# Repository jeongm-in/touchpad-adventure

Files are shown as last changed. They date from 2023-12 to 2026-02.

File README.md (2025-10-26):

# touchpad-adventure

Repurposing [Framework](https://frame.work/)'s [Touchpad module for Framework 13'](https://frame.work/products/touchpad-kit?v=FRANFT0001) as a stand alone device using Raspberry Pi Pico, inspired by [Framework Magic Trackpad](https://community.frame.work/t/framework-magic-trackpad/19453) forum post and [HID articles on Hackaday by Arya Voronova](https://hackaday.com/2024/04/17/human-interfacing-devices-hid-over-i2c/)

## Framework touchpad module
Framework touchpad module is a 115 x 76.6mm glass panel that uses [PixArt PCT3854QR](https://www.pixart.com/products-detail/112/PCT3854QR) controller. Unfortunately PixArt does not provide documentation for this chipset, but it supports HID over I2C which simplifies matters a lot. 

In Framework laptop 13' model, both fingerprint reader and keyboard are connected to the touchpad module. Touchpad module then routes all three fingerprint reader / keyboard / touchpad signals to the motherboard via 51 pin ZIF connector-to-10156001-051100LF connector. Framework provides connector and pinout information on their [GitHub repository](https://github.com/FrameworkComputer/Framework-Laptop-13/tree/main/Touchpad). 

Since this touchpad uses HID over I2C protocol, I'm only interested in 5 out of the 51 pins: TP_SCL (Serial Clock Line), TP_SDA (Serial Data Line), TP_INT (Interrupt, Work in progress to get the INT working), GND, and 5VS.

| Pin | Conn | Signal | Notes|
|-----|----- | --- | ----- |
| 33 | 17 | GND |  |
| 34  | 34 | TP_SCL | Touchpad I2C SCL -- Clock Line|
| 35 | 18 | TP_INT | Touchpad interrupt GPIO | 
| 36 | 33 | TP_SDA | Touchpad I2C SDA -- Data Line | 
| 38 | 32 | 5VS | 5V, Connected to 5VS rail through a 0 ohm resistor |
| 39 | 20 | 5VALW | Fingerprint 5V | 
| 40 | 31 | USB_N | Fingerprint USB | 
| 41 | 21 | GND |  |
| 42 | 20 | USB_P | Fingerprint USB | 
| 37 | 19 | TP_BOARD_ID | |
| 26 | 38 | GND |  |
| 29 | 15 | GND |  |
| 31 | 16 | GND |  |
| 49 | 25 | GND |  | 
| 48 | 27 | FPR_LED_COM | 5V, Fingerprint LED |

Above table shows the pin mapping between the ZIF connector (Pin column) and the 10156001-051100LF connector (Conn column). But since we're not using the 10156001-051100LF connector, this table is not relevant to us. 

Although the pinout says the touchpad module takes 5V input, I found that it works just fine with 3.3V which is found in a lot of microcontrollers. I'll be using Raspberry Pi Pico W for the remainder of this write up. 

## Assembly and probing

I ordered [51 pin ZIF breakout board](https://www.aliexpress.us/item/2251832656865723.html) from AliExpress and soldered headers on it. It looks like I can use any of the numerous GND pins, but I stuck to the one that's closest to my I2C pins. 

| Pin | Breakout board |
| --- |  --- |
| SDA |  36 |
| SCL |  34 | 
| GND |  33 |
| 5V |  40 |
| INT | 35 |

Initially I started out with an [Elite-C](https://deskthority.net/wiki/Elite-C) (Pro-Micro compatible board) running Arduino, because I thought I needed 5V to power the device. After connecting the microcontroller to the touchpad, I used the [I2C scanner sketch](https://playground.arduino.cc/Main/I2cScanner/) to see the available I2C addresses. Framework Touchpad module utilizes two I2C addresses, 0x2C and 0x33:

```
I2C device found at address 0x2C  ! (44)
I2C device found at address 0x33  ! (51)
done
```

Plugging the device to the Raspberry Pi 3B+ and running `i2cdetect` also revealed the same results: 
```
passionfruit@raspberrypi:~ $ i2cdetect -y 1
     0  1  2  3  4  5  6  7  8  9  a  b  c  d  e  f
00:                         -- -- -- -- -- -- -- --
10: -- -- -- -- -- -- -- -- -- -- -- -- -- -- -- --
20: -- -- -- -- -- -- -- -- -- -- -- -- 2c -- -- --
30: -- -- -- 33 -- -- -- -- -- -- -- -- -- -- -- --
40: -- -- -- -- -- -- -- -- -- -- -- -- -- -- -- --
50: -- -- -- -- -- -- -- -- -- -- -- -- -- -- -- --
60: -- -- -- -- -- -- -- -- -- -- -- -- -- -- -- --
70: -- -- -- -- -- -- -- --
```

Additional `i2cdump` results showed that there's something on 0x20 within this address at 0x2C: 

```
passionfruit@raspberrypi:~ $ i2cdump -y 1 0x2c
No size specified (using byte-data access)
     0  1  2  3  4  5  6  7  8  9  a  b  c  d  e  f    0123456789abcdef
00: 00 00 00 00 00 00 00 00 00 00 00 00 00 00 00 00    ................
10: 00 00 00 00 00 00 00 00 00 00 00 00 00 00 00 00    ................
20: 1e 06 00 00 00 00 00 00 00 00 00 00 00 00 00 00    ??..............
30: 00 00 00 00 00 00 00 00 00 00 00 00 00 00 00 00    ................
40: 00 00 00 00 00 00 00 00 00 00 00 00 00 00 00 00    ................
50: 00 00 00 00 00 00 00 00 00 00 00 00 00 00 00 00    ................
60: 00 00 00 00 00 00 00 00 00 00 00 00 00 00 00 00    ................
70: 00 00 00 00 00 00 00 00 00 00 00 00 00 00 00 00    ................
80: 00 00 00 00 00 00 00 00 00 00 00 00 00 00 00 00    ................
90: 00 00 00 00 00 00 00 00 00 00 00 00 00 00 00 00    ................
a0: 00 00 00 00 00 00 00 00 00 00 00 00 00 00 00 00    ................
b0: 00 00 00 00 00 00 00 00 00 00 00 00 00 00 00 00    ................
c0: 00 00 00 00 00 00 00 00 00 00 00 00 00 00 00 00    ................
d0: 00 00 00 00 00 00 00 00 00 00 00 00 00 00 00 00    ................
e0: 00 00 00 00 00 00 00 00 00 00 00 00 00 00 00 00    ................
f0: 00 00 00 00 00 00 00 00 00 00 00 00 00 00 00 00    ................
```

Then by pure luck, I learned that the device works just fine with 3.3V so I switched over to Raspberry Pi Pico W so that I can use micropython instead of Arduino code. This turned out to be a good decision because Arduino's Wire library by default reads less number of bytes than the HID input report sent from the touchpad module. And I was constantly hitting memory limit on Elite-C, though that's probably because my code was horribly inefficient.  

With some trial and error, I wrote some code based on the Python code provided in [Arya's Hackaday article](https://hackaday.com/2024/04/17/human-interfacing-devices-hid-over-i2c/) to read some data out of 0x2c - 0x20 on the touchpad device.

```python
# Scan for connected I2C devices  
import machine

SDA_PIN = machine.Pin(4)
SCL_PIN = machine.Pin(5)
i2c = machine.I2C(0, sda=SDA_PIN, scl=SCL_PIN, freq=500000)

TOUCHPAD_ADDR = 0x2c
REPORT_ID = 0x01 

def helper_function(abc):
    return ([abc[i:i+2] for i in range(0, len(abc), 2)])

def helper_function_to_int(myList):
    k = [int(x, 16) for x in myList]
    v = ["{:03d}".format(x) for x in k]
    return  [str(x) for x in v]

def runner():
    while True:
        try:
            l = i2c.readfrom(TOUCHPAD_ADDR, 1)[0]
            if l:
                d = i2c.readfrom(TOUCHPAD_ADDR, l)
                if d[2] != REPORT_ID:
                    print("WARNING")
                    print(l, d)
                else:
                    d = d[3:]
                    formatted = helper_function(d.hex())
                    output = helper_function_to_int(formatted)
                    print(" ".join(output))
                    
        except OSError:
            print("Nothing burger")

runner()
```

Using this code, I was able to consistently read 30 something bytes long data that changed every time I moved the finger around. It also changed depending on the number of fingers contacting the touchpad surface. This byte array was the actual HID input report sent from the device, but I did not understand what it meant at the time. 

## Finding HID report descriptor and understanding the report 

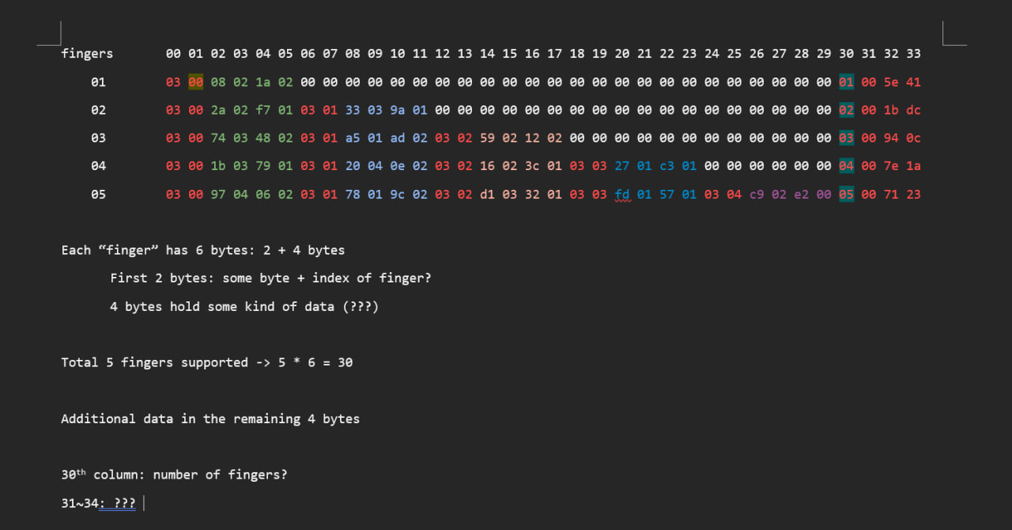
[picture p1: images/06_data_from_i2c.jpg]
table


I made some best effort guesses to figure out what this data meant. But to really understand what is going on, I had to look at the HID report descriptor used by this touchpad device. 

HID Report is nothing more than a binary data sent from the HID device. HID Report descriptor is a schematic for a given HID report, which outlines what each parts of the report's binary data means and describes the range limit of each part. 

I had some data to work with, such as report descriptor data in [Arya's repository](https://github.com/0xAryaCAFE/spicy-micropython/blob/3810a95b423668ce8a7be2f6eb615eec5d33fedd/ports/rp2/tusb_port.c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). Apparently Arya and many other people were already here, but I couldn't readily find a way to turn this module into a stand alone device online.

I also learned that HID device usually stores its HID descriptor on the device so that the host machine can interact with it. I updated my earlier code to "dump" some data from each address under 0x2C. 

```python
def helper_function_to_int(myList):
    k = [int(x, 16) for x in myList]
    v = ["{:03d}".format(x) for x in k]
    return  [str(x) for x in v]

def brute_force():
    for i in range(0, 256):
        l = i2c.readfrom_mem(TOUCHPAD_ADDR, i, 64)
        print(i, " ".join(helper_function(l.hex())))
```

```bash
...
30 00 00 00 01 af 02 21 00 24 00 25 00 25 00 00 00 22 00 23 00 3a 09 74 02 04 07 00 00 00 00 00 00 00 03 00 91 f5 00 00 00 00 00 00 00 00 00 00 00 00 00 00 00 00 00 00 00 00 00 00 00 00 00 00 00
31 00 00 00 01 af 02 21 00 24 00 25 00 25 00 00 00 22 00 23 00 3a 09 74 02 04 07 00 00 00 00 00 00 00 03 00 91 f5 00 00 00 00 00 00 00 00 00 00 00 00 00 00 00 00 00 00 00 00 00 00 00 00 00 00 00

// ↓↓↓↓↓↓↓↓↓↓↓↓↓↓↓↓↓↓↓↓↓↓↓↓↓↓↓↓↓↓↓
32 1e 00 00 01 af 02 21 00 24 00 25 00 25 00 00 00 22 00 23 00 3a 09 74 02 04 07 00 00 00 00 00 00 00 00 00 00 00 00 00 00 00 00 00 00 00 00 00 00 00 00 00 00 00 00 00 00 00 00 00 00 00 00 00 00

// ↓↓↓↓↓↓↓↓↓↓↓↓↓↓↓↓↓↓↓↓↓↓↓↓↓↓↓↓↓↓↓
33 05 01 09 02 a1 01 85 02 05 01 09 01 a1 00 05 09 19 01 29 02 15 00 25 01 75 01 95 02 81 02 05 0d 09 32 75 01 95 01 81 02 75 05 95 01 81 03 05 01 75 10 95 01 35 00 45 00 16 00 80 26 ff 7f 09 30

34 00 00 00 01 af 02 21 00 24 00 25 00 25 00 00 00 22 00 23 00 3a 09 74 02 04 07 00 00 00 00 00 00 00 03 00 91 f5 00 00 00 00 00 00 00 00 00 00 00 00 00 00 00 00 00 00 00 00 00 00 00 00 00 00 00
35 00 00 00 01 af 02 21 00 24 00 25 00 25 00 00 00 22 00 23 00 3a 09 74 02 04 07 00 00 00 00 00 00 00 03 00 91 f5 00 00 00 00 00 00 00 00 00 00 00 00 00 00 00 00 00 00 00 00 00 00 00 00 00 00 00
...
```

And of course, the report descriptor was stored under 0x33. Using [Frank Zhao's USB Descriptor and Request Parser tool](https://eleccelerator.com/usbdescreqparser/), here's the HID report descriptor for the Framework's touchpad module.

```
0x05, 0x01,        // Usage Page (Generic Desktop Ctrls)
0x09, 0x02,        // Usage (Mouse)
0xA1, 0x01,        // Collection (Application)
0x85, 0x02,        //   Report ID (2)
0x05, 0x01,        //   Usage Page (Generic Desktop Ctrls)
0x09, 0x01,        //   Usage (Pointer)
0xA1, 0x00,        //   Collection (Physical)
0x05, 0x09,        //     Usage Page (Button)
0x19, 0x01,        //     Usage Minimum (0x01)
0x29, 0x02,        //     Usage Maximum (0x02)
0x15, 0x00,        //     Logical Minimum (0)
0x25, 0x01,        //     Logical Maximum (1)
0x75, 0x01,        //     Report Size (1)
0x95, 0x02,        //     Report Count (2)
0x81, 0x02,        //     Input (Data,Var,Abs,No Wrap,Linear,Preferred State,No Null Position)
0x05, 0x0D,        //     Usage Page (Digitizer)
0x09, 0x32,        //     Usage (In Range)
0x75, 0x01,        //     Report Size (1)
0x95, 0x01,        //     Report Count (1)
0x81, 0x02,        //     Input (Data,Var,Abs,No Wrap,Linear,Preferred State,No Null Position)
0x75, 0x05,        //     Report Size (5)
0x95, 0x01,        //     Report Count (1)
0x81, 0x03,        //     Input (Const,Var,Abs,No Wrap,Linear,Preferred State,No Null Position)
0x05, 0x01,        //     Usage Page (Generic Desktop Ctrls)
0x75, 0x10,        //     Report Size (16)
0x95, 0x01,        //     Report Count (1)
0x35, 0x00,        //     Physical Minimum (0)
0x45, 0x00,        //     Physical Maximum (0)
0x16, 0x00, 0x80,  //     Logical Minimum (-32768)
0x26, 0xFF, 0x7F,  //     Logical Maximum (32767)
0x09, 0x30,        //     Usage (X)
0x81, 0x26,        //     Input (Data,Var,Rel,No Wrap,Linear,No Preferred State,No Null Position)
0x16, 0x00, 0x80,  //     Logical Minimum (-32768)
0x26, 0xFF, 0x7F,  //     Logical Maximum (32767)
0x09, 0x31,        //     Usage (Y)
0x81, 0x26,        //     Input (Data,Var,Rel,No Wrap,Linear,No Preferred State,No Null Position)
0xC0,              //   End Collection
0xC0,              // End Collection
0x05, 0x0D,        // Usage Page (Digitizer)
0x09, 0x05,        // Usage (Touch Pad)
0xA1, 0x01,        // Collection (Application)
0x85, 0x01,        //   Report ID (1)
0x05, 0x0D,        //   Usage Page (Digitizer)
0x09, 0x22,        //   Usage (Finger)
0xA1, 0x02,        //   Collection (Logical)
0x09, 0x47,        //     Usage (0x47)
0x09, 0x42,        //     Usage (Tip Switch)
0x15, 0x00,        //     Logical Minimum (0)
0x25, 0x01,        //     Logical Maximum (1)
0x75, 0x01,        //     Report Size (1)
0x95, 0x02,        //     Report Count (2)
0x81, 0x02,        //     Input (Data,Var,Abs,No Wrap,Linear,Preferred State,No Null Position)
0x95, 0x06,        //     Report Count (6)
0x81, 0x03,        //     Input (Const,Var,Abs,No Wrap,Linear,Preferred State,No Null Position)
0x09, 0x51,        //     Usage (0x51)
0x25, 0x0F,        //     Logical Maximum (15)
0x75, 0x08,        //     Report Size (8)
0x95, 0x01,        //     Report Count (1)
0x81, 0x02,        //     Input (Data,Var,Abs,No Wrap,Linear,Preferred State,No Null Position)
0x05, 0x01,        //     Usage Page (Generic Desktop Ctrls)
0x09, 0x30,        //     Usage (X)
0x75, 0x10,        //     Report Size (16)
0x55, 0x0E,        //     Unit Exponent (-2)
0x65, 0x11,        //     Unit (System: SI Linear, Length: Centimeter)
0x35, 0x00,        //     Physical Minimum (0)
0x46, 0x5A, 0x04,  //     Physical Maximum (1114)
0x27, 0x39, 0x05, 0x00, 0x00,  //     Logical Maximum (1336)
0x81, 0x02,        //     Input (Data,Var,Abs,No Wrap,Linear,Preferred State,No Null Position)
0x09, 0x31,        //     Usage (Y)
0x46, 0xDA, 0x02,  //     Physical Maximum (730)
0x27, 0x6C, 0x03, 0x00, 0x00,  //     Logical Maximum (875)
0x81, 0x02,        //     Input (Data,Var,Abs,No Wrap,Linear,Preferred State,No Null Position)
0xC0,              //   End Collection
0x05, 0x0D,        //   Usage Page (Digitizer)
0x09, 0x22,        //   Usage (Finger)
0xA1, 0x02,        //   Collection (Logical)
0x09, 0x47,        //     Usage (0x47)
0x09, 0x42,        //     Usage (Tip Switch)
0x15, 0x00,        //     Logical Minimum (0)
0x25, 0x01,        //     Logical Maximum (1)
0x75, 0x01,        //     Report Size (1)
0x95, 0x02,        //     Report Count (2)
0x81, 0x02,        //     Input (Data,Var,Abs,No Wrap,Linear,Preferred State,No Null Position)
0x95, 0x06,        //     Report Count (6)
0x81, 0x03,        //     Input (Const,Var,Abs,No Wrap,Linear,Preferred State,No Null Position)
0x09, 0x51,        //     Usage (0x51)
0x25, 0x0F,        //     Logical Maximum (15)
0x75, 0x08,        //     Report Size (8)
0x95, 0x01,        //     Report Count (1)
0x81, 0x02,        //     Input (Data,Var,Abs,No Wrap,Linear,Preferred State,No Null Position)
0x05, 0x01,        //     Usage Page (Generic Desktop Ctrls)
0x09, 0x30,        //     Usage (X)
0x75, 0x10,        //     Report Size (16)
0x55, 0x0E,        //     Unit Exponent (-2)
0x65, 0x11,        //     Unit (System: SI Linear, Length: Centimeter)
0x35, 0x00,        //     Physical Minimum (0)
0x46, 0x5A, 0x04,  //     Physical Maximum (1114)
0x27, 0x39, 0x05, 0x00, 0x00,  //     Logical Maximum (1336)
0x81, 0x02,        //     Input (Data,Var,Abs,No Wrap,Linear,Preferred State,No Null Position)
0x09, 0x31,        //     Usage (Y)
0x46, 0xDA, 0x02,  //     Physical Maximum (730)
0x27, 0x6C, 0x03, 0x00, 0x00,  //     Logical Maximum (875)
0x81, 0x02,        //     Input (Data,Var,Abs,No Wrap,Linear,Preferred State,No Null Position)
0xC0,              //   End Collection
0x05, 0x0D,        //   Usage Page (Digitizer)
0x09, 0x22,        //   Usage (Finger)
0xA1, 0x02,        //   Collection (Logical)
0x09, 0x47,        //     Usage (0x47)
0x09, 0x42,        //     Usage (Tip Switch)
0x15, 0x00,        //     Logical Minimum (0)
0x25, 0x01,        //     Logical Maximum (1)
0x75, 0x01,        //     Report Size (1)
0x95, 0x02,        //     Report Count (2)
0x81, 0x02,        //     Input (Data,Var,Abs,No Wrap,Linear,Preferred State,No Null Position)
0x95, 0x06,        //     Report Count (6)
0x81, 0x03,        //     Input (Const,Var,Abs,No Wrap,Linear,Preferred State,No Null Position)
0x09, 0x51,        //     Usage (0x51)
0x25, 0x0F,        //     Logical Maximum (15)
0x75, 0x08,        //     Report Size (8)
0x95, 0x01,        //     Report Count (1)
0x81, 0x02,        //     Input (Data,Var,Abs,No Wrap,Linear,Preferred State,No Null Position)
0x05, 0x01,        //     Usage Page (Generic Desktop Ctrls)
0x09, 0x30,        //     Usage (X)
0x75, 0x10,        //     Report Size (16)
0x55, 0x0E,        //     Unit Exponent (-2)
0x65, 0x11,        //     Unit (System: SI Linear, Length: Centimeter)
0x35, 0x00,        //     Physical Minimum (0)
0x46, 0x5A, 0x04,  //     Physical Maximum (1114)
0x27, 0x39, 0x05, 0x00, 0x00,  //     Logical Maximum (1336)
0x81, 0x02,        //     Input (Data,Var,Abs,No Wrap,Linear,Preferred State,No Null Position)
0x09, 0x31,        //     Usage (Y)
0x46, 0xDA, 0x02,  //     Physical Maximum (730)
0x27, 0x6C, 0x03, 0x00, 0x00,  //     Logical Maximum (875)
0x81, 0x02,        //     Input (Data,Var,Abs,No Wrap,Linear,Preferred State,No Null Position)
0xC0,              //   End Collection
0x05, 0x0D,        //   Usage Page (Digitizer)
0x09, 0x22,        //   Usage (Finger)
0xA1, 0x02,        //   Collection (Logical)
0x09, 0x47,        //     Usage (0x47)
0x09, 0x42,        //     Usage (Tip Switch)
0x15, 0x00,        //     Logical Minimum (0)
0x25, 0x01,        //     Logical Maximum (1)
0x75, 0x01,        //     Report Size (1)
0x95, 0x02,        //     Report Count (2)
0x81, 0x02,        //     Input (Data,Var,Abs,No Wrap,Linear,Preferred State,No Null Position)
0x95, 0x06,        //     Report Count (6)
0x81, 0x03,        //     Input (Const,Var,Abs,No Wrap,Linear,Preferred State,No Null Position)
0x09, 0x51,        //     Usage (0x51)
0x25, 0x0F,        //     Logical Maximum (15)
0x75, 0x08,        //     Report Size (8)
0x95, 0x01,        //     Report Count (1)
0x81, 0x02,        //     Input (Data,Var,Abs,No Wrap,Linear,Preferred State,No Null Position)
0x05, 0x01,        //     Usage Page (Generic Desktop Ctrls)
0x09, 0x30,        //     Usage (X)
0x75, 0x10,        //     Report Size (16)
0x55, 0x0E,        //     Unit Exponent (-2)
0x65, 0x11,        //     Unit (System: SI Linear, Length: Centimeter)
0x35, 0x00,        //     Physical Minimum (0)
0x46, 0x5A, 0x04,  //     Physical Maximum (1114)
0x27, 0x39, 0x05, 0x00, 0x00,  //     Logical Maximum (1336)
0x81, 0x02,        //     Input (Data,Var,Abs,No Wrap,Linear,Preferred State,No Null Position)
0x09, 0x31,        //     Usage (Y)
0x46, 0xDA, 0x02,  //     Physical Maximum (730)
0x27, 0x6C, 0x03, 0x00, 0x00,  //     Logical Maximum (875)
0x81, 0x02,        //     Input (Data,Var,Abs,No Wrap,Linear,Preferred State,No Null Position)
0xC0,              //   End Collection
0x05, 0x0D,        //   Usage Page (Digitizer)
0x09, 0x22,        //   Usage (Finger)
0xA1, 0x02,        //   Collection (Logical)
0x09, 0x47,        //     Usage (0x47)
0x09, 0x42,        //     Usage (Tip Switch)
0x15, 0x00,        //     Logical Minimum (0)
0x25, 0x01,        //     Logical Maximum (1)
0x75, 0x01,        //     Report Size (1)
0x95, 0x02,        //     Report Count (2)
0x81, 0x02,        //     Input (Data,Var,Abs,No Wrap,Linear,Preferred State,No Null Position)
0x95, 0x06,        //     Report Count (6)
0x81, 0x03,        //     Input (Const,Var,Abs,No Wrap,Linear,Preferred State,No Null Position)
0x09, 0x51,        //     Usage (0x51)
0x25, 0x0F,        //     Logical Maximum (15)
0x75, 0x08,        //     Report Size (8)
0x95, 0x01,        //     Report Count (1)
0x81, 0x02,        //     Input (Data,Var,Abs,No Wrap,Linear,Preferred State,No Null Position)
0x05, 0x01,        //     Usage Page (Generic Desktop Ctrls)
0x09, 0x30,        //     Usage (X)
0x75, 0x10,        //     Report Size (16)
0x55, 0x0E,        //     Unit Exponent (-2)
0x65, 0x11,        //     Unit (System: SI Linear, Length: Centimeter)
0x35, 0x00,        //     Physical Minimum (0)
0x46, 0x5A, 0x04,  //     Physical Maximum (1114)
0x27, 0x39, 0x05, 0x00, 0x00,  //     Logical Maximum (1336)
0x81, 0x02,        //     Input (Data,Var,Abs,No Wrap,Linear,Preferred State,No Null Position)
0x09, 0x31,        //     Usage (Y)
0x46, 0xDA, 0x02,  //     Physical Maximum (730)
0x27, 0x6C, 0x03, 0x00, 0x00,  //     Logical Maximum (875)
0x81, 0x02,        //     Input (Data,Var,Abs,No Wrap,Linear,Preferred State,No Null Position)
0xC0,              //   End Collection
0x05, 0x0D,        //   Usage Page (Digitizer)
0x09, 0x54,        //   Usage (0x54)
0x15, 0x00,        //   Logical Minimum (0)
0x25, 0x05,        //   Logical Maximum (5)
0x75, 0x08,        //   Report Size (8)
0x95, 0x01,        //   Report Count (1)
0x81, 0x02,        //   Input (Data,Var,Abs,No Wrap,Linear,Preferred State,No Null Position)
0x05, 0x09,        //   Usage Page (Button)
0x09, 0x01,        //   Usage (0x01)
0x09, 0x02,        //   Usage (0x02)
0x09, 0x03,        //   Usage (0x03)
0x15, 0x00,        //   Logical Minimum (0)
0x25, 0x01,        //   Logical Maximum (1)
0x75, 0x01,        //   Report Size (1)
0x95, 0x03,        //   Report Count (3)
0x81, 0x02,        //   Input (Data,Var,Abs,No Wrap,Linear,Preferred State,No Null Position)
0x95, 0x05,        //   Report Count (5)
0x81, 0x03,        //   Input (Const,Var,Abs,No Wrap,Linear,Preferred State,No Null Position)
0x05, 0x0D,        //   Usage Page (Digitizer)
0x09, 0x56,        //   Usage (0x56)
0x55, 0x0C,        //   Unit Exponent (-4)
0x66, 0x01, 0x10,  //   Unit (System: SI Linear, Time: Seconds)
0x35, 0x00,        //   Physical Minimum (0)
0x47, 0xFF, 0xFF, 0x00, 0x00,  //   Physical Maximum (65534)
0x15, 0x00,        //   Logical Minimum (0)
0x27, 0xFF, 0xFF, 0x00, 0x00,  //   Logical Maximum (65534)
0x75, 0x10,        //   Report Size (16)
0x95, 0x01,        //   Report Count (1)
0x81, 0x02,        //   Input (Data,Var,Abs,No Wrap,Linear,Preferred State,No Null Position)
0x05, 0x0D,        //   Usage Page (Digitizer)
0x09, 0x55,        //   Usage (0x55)
0x15, 0x00,        //   Logical Minimum (0)
0x25, 0x05,        //   Logical Maximum (5)
0x75, 0x08,        //   Report Size (8)
0x95, 0x01,        //   Report Count (1)
0x85, 0x03,        //   Report ID (3)
0xB1, 0x02,        //   Feature (Data,Var,Abs,No Wrap,Linear,Preferred State,No Null Position,Non-volatile)
0x05, 0x0D,        //   Usage Page (Digitizer)
0x09, 0x59,        //   Usage (0x59)
0x15, 0x00,        //   Logical Minimum (0)
0x25, 0x0F,        //   Logical Maximum (15)
0x75, 0x08,        //   Report Size (8)
0x95, 0x01,        //   Report Count (1)
0x85, 0x04,        //   Report ID (4)
0xB1, 0x02,        //   Feature (Data,Var,Abs,No Wrap,Linear,Preferred State,No Null Position,Non-volatile)
0x06, 0x00, 0xFF,  //   Usage Page (Vendor Defined 0xFF00)
0x85, 0x05,        //   Report ID (5)
0x75, 0x08,        //   Report Size (8)
0x15, 0x00,        //   Logical Minimum (0)
0x09, 0xC6,        //   Usage (0xC6)
0x25, 0x08,        //   Logical Maximum (8)
0x95, 0x01,        //   Report Count (1)
0xB1, 0x02,        //   Feature (Data,Var,Abs,No Wrap,Linear,Preferred State,No Null Position,Non-volatile)
0x09, 0xC7,        //   Usage (0xC7)
0x26, 0xFF, 0x00,  //   Logical Maximum (255)
0x95, 0x20,        //   Report Count (32)
0xB1, 0x02,        //   Feature (Data,Var,Abs,No Wrap,Linear,Preferred State,No Null Position,Non-volatile)
0xC0,              // End Collection
0x05, 0x0D,        // Usage Page (Digitizer)
0x09, 0x0E,        // Usage (0x0E)
0xA1, 0x01,        // Collection (Application)
0x05, 0x0D,        //   Usage Page (Digitizer)
0x09, 0x22,        //   Usage (Finger)
0xA1, 0x02,        //   Collection (Logical)
0x09, 0x52,        //     Usage (0x52)
0x15, 0x00,        //     Logical Minimum (0)
0x25, 0x0A,        //     Logical Maximum (10)
0x75, 0x08,        //     Report Size (8)
0x95, 0x01,        //     Report Count (1)
0x85, 0x06,        //     Report ID (6)
0xB1, 0x02,        //     Feature (Data,Var,Abs,No Wrap,Linear,Preferred State,No Null Position,Non-volatile)
0xC0,              //   End Collection
0x05, 0x0D,        //   Usage Page (Digitizer)
0x09, 0x22,        //   Usage (Finger)
0xA1, 0x00,        //   Collection (Physical)
0x09, 0x57,        //     Usage (0x57)
0x09, 0x58,        //     Usage (0x58)
0x15, 0x00,        //     Logical Minimum (0)
0x25, 0x01,        //     Logical Maximum (1)
0x75, 0x01,        //     Report Size (1)
0x95, 0x02,        //     Report Count (2)
0x85, 0x07,        //     Report ID (7)
0xB1, 0x02,        //     Feature (Data,Var,Abs,No Wrap,Linear,Preferred State,No Null Position,Non-volatile)
0x95, 0x06,        //     Report Count (6)
0xB1, 0x03,        //     Feature (Const,Var,Abs,No Wrap,Linear,Preferred State,No Null Position,Non-volatile)
0xC0,              //   End Collection
0x05, 0x0D,        //   Usage Page (Digitizer)
0x09, 0x60,        //   Usage (0x60)
0x15, 0x00,        //   Logical Minimum (0)
0x25, 0x01,        //   Logical Maximum (1)
0x75, 0x01,        //   Report Size (1)
0x95, 0x01,        //   Report Count (1)
0x85, 0x08,        //   Report ID (8)
0xB1, 0x02,        //   Feature (Data,Var,Abs,No Wrap,Linear,Preferred State,No Null Position,Non-volatile)
0x95, 0x07,        //   Report Count (7)
0xB1, 0x03,        //   Feature (Const,Var,Abs,No Wrap,Linear,Preferred State,No Null Position,Non-volatile)
0xC0,              // End Collection
0x06, 0x00, 0xFF,  // Usage Page (Vendor Defined 0xFF00)
0x09, 0x01,        // Usage (0x01)
0xA1, 0x01,        // Collection (Application)
0x85, 0x42,        //   Report ID (66)
0x09, 0x06,        //   Usage (0x06)
0x15, 0x00,        //   Logical Minimum (0)
0x26, 0xFF, 0x00,  //   Logical Maximum (255)
0x75, 0x08,        //   Report Size (8)
0x95, 0x03,        //   Report Count (3)
0xB1, 0x02,        //   Feature (Data,Var,Abs,No Wrap,Linear,Preferred State,No Null Position,Non-volatile)
0x06, 0x00, 0xFF,  //   Usage Page (Vendor Defined 0xFF00)
0x09, 0x05,        //   Usage (0x05)
0x15, 0x00,        //   Logical Minimum (0)
0x26, 0xFF, 0x00,  //   Logical Maximum (255)
0x75, 0x08,        //   Report Size (8)
0x96, 0x00, 0x01,  //   Report Count (256)
0x85, 0x41,        //   Report ID (65)
0xB1, 0x02,        //   Feature (Data,Var,Abs,No Wrap,Linear,Preferred State,No Null Position,Non-volatile)
0x85, 0x43,        //   Report ID (67)
0x09, 0x06,        //   Usage (0x06)
0x15, 0x00,        //   Logical Minimum (0)
0x26, 0xFF, 0x00,  //   Logical Maximum (255)
0x75, 0x08,        //   Report Size (8)
0x95, 0x03,        //   Report Count (3)
0xB1, 0x02,        //   Feature (Data,Var,Abs,No Wrap,Linear,Preferred State,No Null Position,Non-volatile)
0xC0,              // End Collection

// 687 bytes

```

In addition to the report descriptor, I found that register 0x20 holds [Required I2C HID Descriptor](https://learn.microsoft.com/en-us/windows-hardware/design/component-guidelines/touchpad-required-hid-descriptors) information. 

| Member | Size in Bytes | Description | value in hex | value in dec or decoded |
| ---- | ---- | ---- | ---- | ---- |
| wHIDDescLength | 2 | The length of the complete HID descriptor (in Bytes) |  `1e 00` = `0x001e` | 30 |
| bcdVersion | 2 | The version number, in binary coded decimal format | `00 01` = `0x0100` | 4 |
| wReportDescLength | 2 | The length of the Report descriptor (in Bytes) | `af 02` = `0x02af` | 687 |
| wReportDescRegister | 2 | The register index containing the report descriptor | `21 00` = `0x21` | 33 |
| wInputRegister | 2 | The register number to read the input report | `24 00` = `0x24` | 36 | 
| wMaxInputLength | 2 | The length of the largest input report to be read from the input register | `25 00` = `0x25` | 37 |
| wOutputRegister | 2 | The register number to send the output | `25 00` = `0x25` | 37 |
| wMaxOutputLength | 2 | The length of the largest output report to be sent | `00 00` = `0x00` | 0 |
| wCommandRegister | 2 | The register number to send command requests | `22 00` = `0x22` | 34 |
| wDataRegister | 2 | The register number to exchange data with command requests | `23 00` = `0x23` | 35 | 
| wVendorID | 2 | USB-IF assigned Vendor ID | `3a 09` = `0x093a` | 2362 |
| wDeviceID | 2 | Device ID | `74 02` = `0x0274` | 628 | 
| wVersionID | 2 | Firmware version number | `04 07` = `0x0704` | 1796 |

All in all, these addresses hold the key information: 

Address: 0x2C
- 0x20: Required I2C HID Descriptor
- 0x21: HID Input Report Descriptor
- 0x24: HID Input Report 

And using the HID report descriptor, I now know what each parts of my report means. 

Each finger gets 6 bytes: 

| Finger <N> Confidence + Tip Switch | Finger <N> index | Finger <N> X Lower Byte | Finger <N> X Higher Byte | Finger <N> Y  Lower Byte | Finger <N> Y Higher Byte | 
|---|---|---|---|---|---|
|03 | 00 | f3 | 04 | 37 | 00 |

And the remaining bytes in the report shows contact count (number of fingers detected) and scan time.

The complete descriptor table looks like this: 

| | index | example |
|---|---|---|
| Finger 0 Confidence + Tip Switch | 00 | 03 |
| Finger 0 index | 01 | 00 |
| Finger 0 X Lower Byte | 02 | f3 |
| Finger 0 X Higher Byte | 03 | 04 |
| Finger 0 Y Lower Byte | 04 | 37 |
| Finger 0 Y Higher Byte | 05 | 00 |
| Finger 1 Confidence + Tip Switch | 06 | 03 |
| Finger 1 index | 07 | 01 |
| Finger 1 X Lower Byte | 08 | f3 |
| Finger 1 X Higher Byte | 09 | 04 |
| Finger 1 Y Lower Byte | 10 | 37 |
| Finger 1 Y Higher Byte | 11 | 00 |
| Finger 2 Confidence + Tip Switch | 12 | 03 |
| Finger 2 index | 13 | 02 |
| Finger 2 X Lower Byte | 14 | f3 |
| Finger 2 X Higher Byte | 15 | 04 |
| Finger 2 Y Lower Byte | 16 | 37 |
| Finger 2 Y Higher Byte | 17 | 00 |
| Finger 3 Confidence + Tip Switch | 18 | 03 |
| Finger 3 index | 19 | 03 |
| Finger 3 X Lower Byte | 20 | f3 |
| Finger 3 X Higher Byte | 21 | 04 |
| Finger 3 Y Lower Byte | 22 | 37 |
| Finger 3 Y Higher Byte | 23 | 00 |
| Finger 4 Confidence + Tip Switch | 24 | 03 |
| Finger 4 index | 25 | 04 |
| Finger 4 X Lower Byte | 26 | f3 |
| Finger 4 X Higher Byte | 27 | 04 |
| Finger 4 Y Lower Byte | 28 | 37 |
| Finger 4 Y Higher Byte | 29 | 00 |
| Number of fingers (Contact Count) | 30 | 05 |
| Number of Buttons pressed | 31 | 00 |
| Scan time lower byte | 32 | e2 |
| Scan time higher byte | 33 | d5 |

## Putting everything together

Now that I have the descriptor and where to find the report, it's time to actually put everything together and send the report to the host system. I thought I had to read the HID report and then convert it into some kind of mouse movement within the microcontroller code, but it turns out I can simply forward the HID report and the host system can pick up whatever signal I'm sending to the touchpad. 

Starting in Micropython version 1.23, [Micropython supports USB device mode](https://github.com/micropython/micropython-lib/tree/master/micropython/usb) that allows using Raspberry Pi Pico as USB HID device. By combining my existing code and the sample [mouse.py](https://github.com/micropython/micropython-lib/blob/master/micropython/usb/usb-device-mouse/usb/device/mouse.py) within the library, I now have the following firmware code (also available in [firwmare directory](https://github.com/jeongm-in/touchpad-adventure/blob/main/firmware))

- prerequsite: needs `usb-device-hid` package

And by simply plugging my Raspberry Pi Pico into my Fedora 41, I can move the cursor around and use all of the gestures supported in this touchpad. 

## Verification 
In Fedora 41, I verified my Raspberry Pi Pico W shows up under `lsusb`: 

```bash
$ lsusb
Bus 005 Device 012: ID 2e8a:0005 MicroPython Board in FS mode
```

HID descriptor reported from the device looks fine: 

```bash
$ usbhid-dump -d2e8a:0005 -ed
005:012:002:DESCRIPTOR         1734844197.053573
 05 0D 09 05 A1 01 85 01 05 0D 09 22 A1 02 09 47
 09 42 15 00 25 01 75 01 95 02 81 02 95 06 81 03
 09 51 25 0F 75 08 95 01 81 02 05 01 09 30 75 10
 55 0E 65 11 35 00 46 5A 04 27 39 05 00 00 81 02
 09 31 46 DA 02 27 6C 03 00 00 81 02 C0 05 0D 09
 22 A1 02 09 47 09 42 15 00 25 01 75 01 95 02 81
 02 95 06 81 03 09 51 25 0F 75 08 95 01 81 02 05
 01 09 30 75 10 55 0E 65 11 35 00 46 5A 04 27 39
 05 00 00 81 02 09 31 46 DA 02 27 6C 03 00 00 81
 02 C0 05 0D 09 22 A1 02 09 47 09 42 15 00 25 01
 75 01 95 02 81 02 95 06 81 03 09 51 25 0F 75 08
 95 01 81 02 05 01 09 30 75 10 55 0E 65 11 35 00
 46 5A 04 27 39 05 00 00 81 02 09 31 46 DA 02 27
 6C 03 00 00 81 02 C0 05 0D 09 22 A1 02 09 47 09
 42 15 00 25 01 75 01 95 02 81 02 95 06 81 03 09
 51 25 0F 75 08 95 01 81 02 05 01 09 30 75 10 55
 0E 65 11 35 00 46 5A 04 27 39 05 00 00 81 02 09
 31 46 DA 02 27 6C 03 00 00 81 02 C0 05 0D 09 22
 A1 02 09 47 09 42 15 00 25 01 75 01 95 02 81 02
 95 06 81 03 09 51 25 0F 75 08 95 01 81 02 05 01
 09 30 75 10 55 0E 65 11 35 00 46 5A 04 27 39 05
 00 00 81 02 09 31 46 DA 02 27 6C 03 00 00 81 02
 C0 05 0D 09 54 15 00 25 05 75 08 95 01 81 02 05
 09 09 01 09 02 09 03 15 00 25 01 75 01 95 03 81
 02 95 05 81 03 05 0D 09 56 55 0C 66 01 10 35 00
 47 FF FF 00 00 15 00 27 FF FF 00 00 75 10 95 01
 81 02
```

And finally, the report looks good (and works): 

```bash
$ usbhid-dump -d2e8a:0005 -es
005:012:002:STREAM             1734843878.706360
 01 03 00 24 05 1E 00 00

005:012:002:STREAM             1734843878.714355
 00 00 00 00 00 00 00 00

005:012:002:STREAM             1734843878.722349
 00 00 00 00 00 00 00 00

005:012:002:STREAM             1734843878.730613
 00 00 00 00 00 00 00 01

005:012:002:STREAM             1734843878.738339
 00 BC 00
```

## Next steps 

- [ ] Touchpad currently does not work on Windows. Need to find out why it's not working and come up with a fix (driver issue?) 
- [x] Current firmware code relies on polling. Touchpad has Interrupt pin, so I assume interrupt based report is possible. 
  - done, but needs to optimize as interrupt is buggy. 
- Design a custom PCB with smaller footprint that integrates both RP2040 (complete RPI Pico board?) and the ZIF breakout for the 5 pins. 
- Design a 3D printed enclosure to mount the PCB and touchpad module. 

## Stretch goals 
- Wireless report transfer (ESP32?)
- Add Fingerprint sensor (could be a standalone project)

## FT260?
I was reading more into FT260 (and to make use of the evaluation board I purchased), as it should in theory achieve what I'm doing with Pi Pico here. However, according to spec sheet, [the max report descriptor size supported by FT260S is 500 bytes](https://ftdichip.com/wp-content/uploads/2020/08/AN_399_FT260_HID-over-I2C.pdf), when our report descriptor size is 687 bytes long. Too bad. 

> The length, in unsigned bytes, of the Report Descriptor. Please note that FT260 only supports maximum size of 500 bytes

## May 2025 update 
Just to cross the finish line, I am not designing a custom PCB at this point; instead I'm using the 51 pin breakout board and WaveShare Pi Zero directly. I have been working on a 3D printed enclosure for the touchpad, and once I'm done prototyping, I will upload models and bill of material (I am using some screws and magnets) to this repository. However, the firmware is very clunky and almost unusable. Thankfully WaveShare Pi Zero has reset button, so I've been punching reset button whenever touchpad glitches out. But once I put everything in enclosure, I will lose access to the reset button unless I add another switch elsewhere. I will need to refine the firmware and see if I can make it better.. 

## October 2025 update
This is my 3D printed enclosure for this project. 

inside

Here the breakout board and the microcontroller is directly fixed to the cutout. 

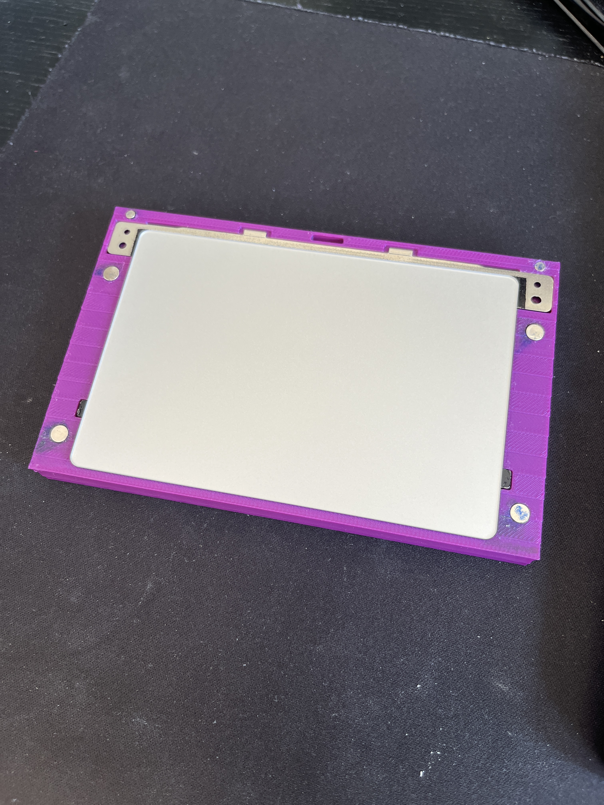
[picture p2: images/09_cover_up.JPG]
cover


When assembled, it would look like this. I added some holes to insert magnets for the top cover. 

fully_assembled

Top cover can be printed in any color for further customization. 

A lot more to work to do on the firmware for better driver support, but rudimentary point and click works. 

# October 26 2025 
Looks like Framework published the full HID descriptor and the HID Report definitions! 

https://github.com/FrameworkComputer/Framework-Laptop-13/blob/main/Touchpad/Firmware.md 

Glad to see the actual HID documentation is now available on their repository :)

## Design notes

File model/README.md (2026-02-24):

Model is available on Onshape at: [Touchpad Enclosure](https://cad.onshape.com/documents/951ed206985eb6aa6d5267c4/w/929f00f12b2a3ae0e2295237/e/c5a4baf2c1e94817fbf0f152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)

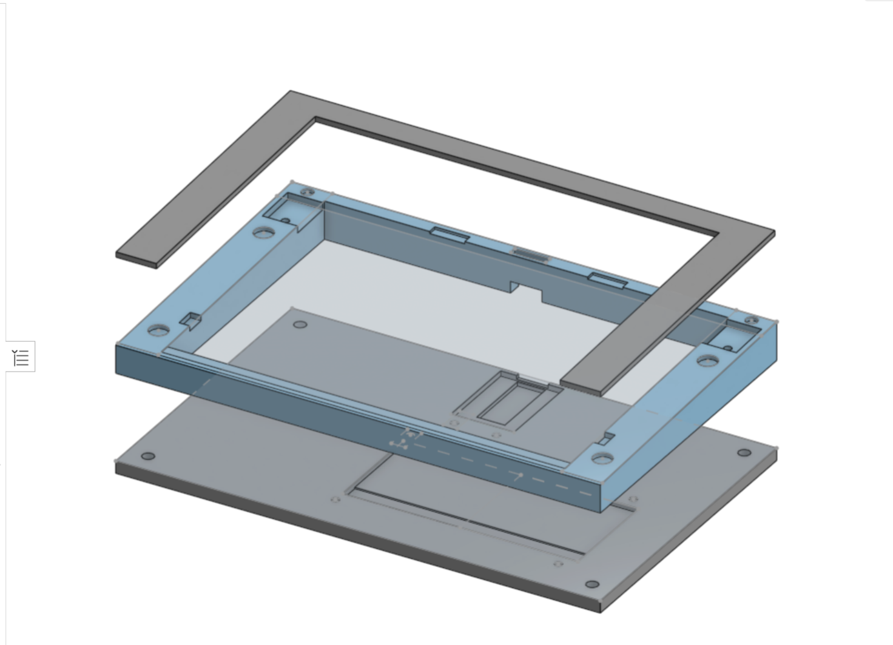
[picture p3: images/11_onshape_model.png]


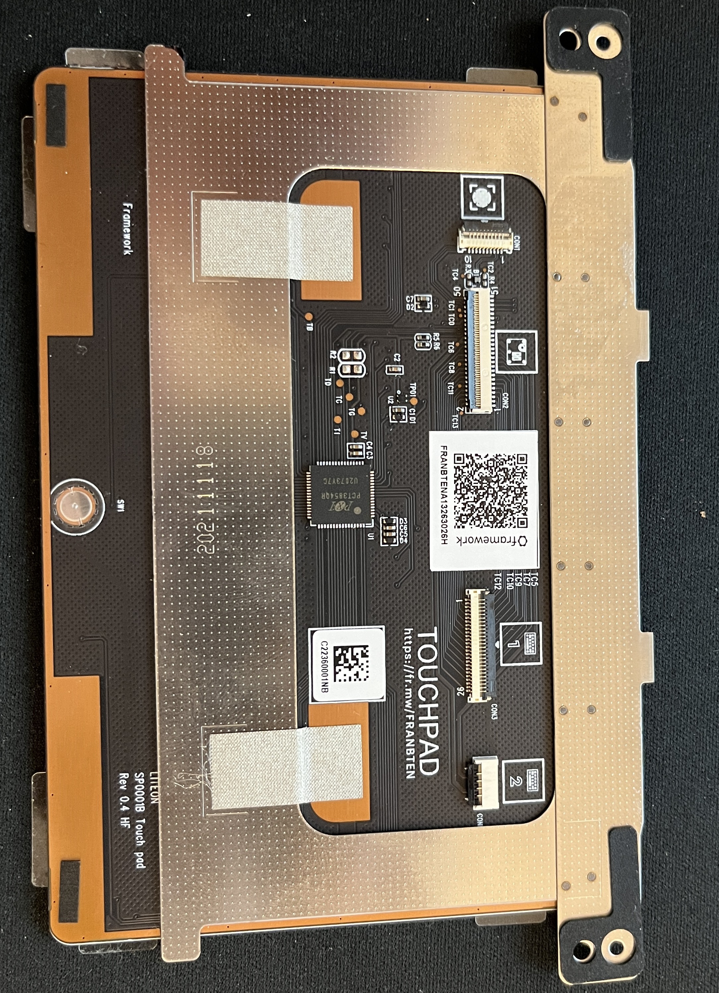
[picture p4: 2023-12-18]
images/01_board.JPG

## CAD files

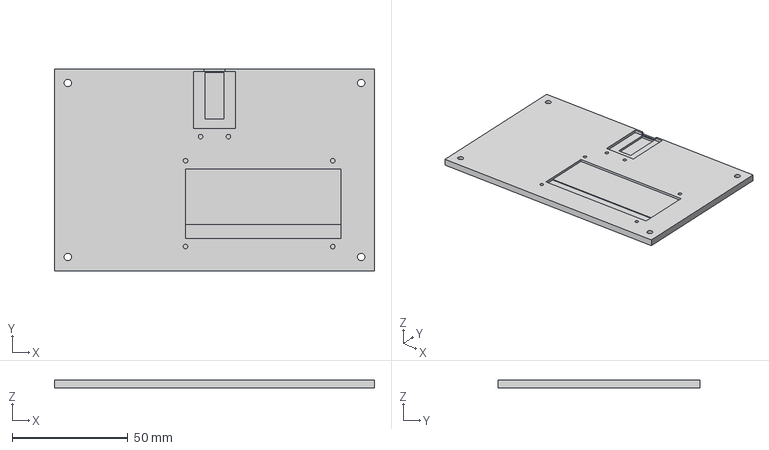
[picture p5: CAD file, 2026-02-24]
model/Touchpad Enclosure - Bottom plate.3mf
138.0 x 87.0 x 3.50 mm

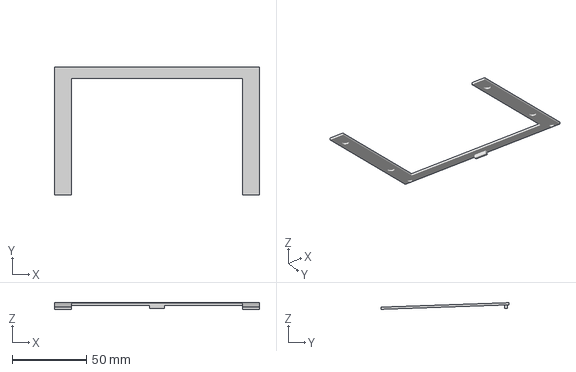
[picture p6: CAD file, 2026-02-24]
model/Touchpad Enclosure - Top Cover.3mf
138.0 x 86.0 x 4.50 mm

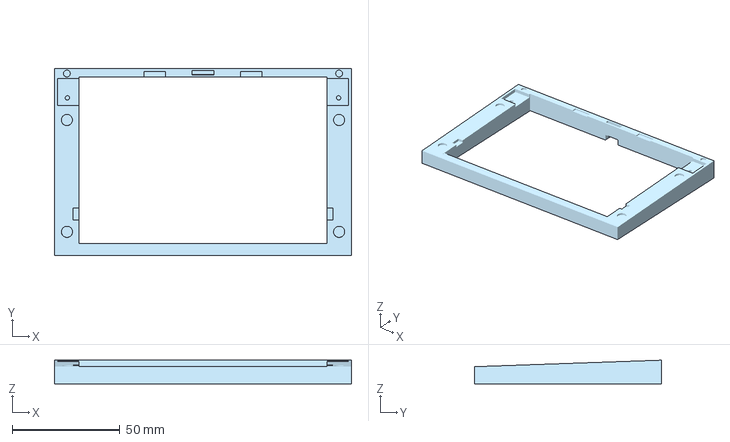
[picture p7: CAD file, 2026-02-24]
model/Touchpad Enclosure - Enclosure.3mf
138.0 x 87.0 x 11.0 mm

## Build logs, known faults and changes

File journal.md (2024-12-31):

Development journal 

---- 

# touchpad-adventure

I've been obsessed with the [Framework Laptop](https://frame.work/) lately, especially after they announced the AMD model. However, I could not justify the purchase because I have a perfectly fine 2018 LG Gram. 
One day I was browsing Framework's parts shop and saw this [touchpad module](https://frame.work/products/touchpad-kit?v=FRANFT0001). I am also obsessed with touchpads, and I really like Apple's Trackpads. However, buying a MacBook is even more unjustifiable (although M series chips are pretty intriguing...). The problem is, there is absolutely no market for decent standalone touch pad input devices out there. So I thought, why not make one myself? 

I impulse bought the touchpad module without much thinking (this was much easier to justify. After all, it's not nearly $1000). After placing my order, I looked up the data sheets and learned that this particular touchpad module uses I2C. Good news is, I have a lot of Arduino and Arduino compatible microcontrollers lying around in my drawer from my custom keyboard phase (everyone goes through one, right?). Though I absolutely had no idea how I will connect the part and the microcontroller, but surely somebody out there would have done something neat with the touchpad module. 

Apparently touchpad is really niche! I found exactly "two" posts, [one from reddit](https://www.reddit.com/r/framework/comments/10yy99y/could_i_build_a_stand_alone_touchpad_using_the/) and [another from Framework forum](https://community.frame.work/t/framework-magic-trackpad/19453) about making a stand alone touchpad input device from Framework's touchpad kit. And none of them was step by step guide on how to make one yourself. I did find [a cool PCB made by Arya](https://www.tindie.com/products/crimier/framework-input-cover-controller/) that connects to the entire keyboard module (keyboard + touchpad + fingerprint sensor) using rpi2040 and turns it into a stand alone keyboard. While it was really cool, this was a keyboard and fingerprint sensor more than what I was trying to make.

So I started actually reading through the documentation to figure out what exactly did I sign myself up to. 

Framework's touchpad module has multiple female connectors that connect to Fingerprint sensor and keyboard. It then connects to the motherboard directly via a 51 pin ZIF female connector to 10156001-051100LF male connector. I think this means I can also order a fingerprint module, connect to the touchpad module, somehow figure out the wiring, ????, and profit, I have a touchpad & fingerprint reader. But I have a very sweaty palm and have a lot of trouble with finger print readers, so I'll reserve that for another time. 

For the I2C though, I need 4 connections: SCL (Clock), SDA (Data), Power Supply (5V), and GND (Ground). According to the [Framework official documentation](https://github.com/FrameworkComputer/Framework-Laptop-13/tree/main/Touchpad), each pin is connected to pins 34, 33, 32, and several (17, 21, 38, 15, 16, 25, 27). So the touchpad module requires 5V.

| Pin | Conn | Signal | Notes|
|-----|----- | --- | ----- |
| 33 | 17 | GND |  |
| 34  | 34 | TP_SCL | Touchpad I2C SCL -- Clock Line|
| 35 | 18 | TP_INT | Touchpad interrupt GPIO | 
| 36 | 33 | TP_SDA | Touchpad I2C SDA -- Data Line | 
| 38 | 32 | 5VS | 5V, Connected to 5VS rail through a 0 ohm resistor |
| 39 | 20 | 5VALW | Fingerprint 5V | 
| 40 | 31 | USB_N | Fingerprint USB | 
| 41 | 21 | GND |  |
| 42 | 20 | USB_P | Fingerprint USB | 
| 37 | 19 | TP_BOARD_ID | |
| 26 | 38 | GND |  |
| 29 | 15 | GND |  |
| 31 | 16 | GND |  |
| 49 | 25 | GND |  | 
| 48 | 27 | FPR_LED_COM | 5V, Fingerprint LED |

Since Arya used rpi2040, I was hoping to finally find some use for my [Raspberry Pi Pico](https://www.raspberrypi.com/products/raspberry-pi-pico/) which I bought for no reason, but alas Raspberry Pi Pico only supports 3.3V. Fortunately though, I had a couple [Elite C](https://deskthority.net/wiki/Elite-C) microcontrollers that do have 5V and all the I2C pins. 

So now I have the touchpad module, I know which pins I need to connect to, and I know which pins on the microcontroller I need to connect my pins to. I have no clue hat kind of code I would need to get the trackpad signal to cursor movement though. 
The touchpad module did come with a cable that connects to the motherboard. I thought about purchasing [a female breakout board](https://oshpark.com/shared_projects/MjMFKhqM), but the cable was a bit to bulky and would have restricted the final housing a lot. So I decided to ditch the cable it came with, and ordered a [51 pin ZIF breakout board from AliExpress](https://www.aliexpress.us/item/2251832656865723.html). Now it says it will take 2 weeks to arrive, but who knows when I would get it in mail. Once I get the part in mail (I'm thinking next year), I will need to solder the pins and cables. Yay... 

All I can do now is just waiting, and maybe doing some research on the software side of things. 

## 2023/12/18

Parts have arrived.

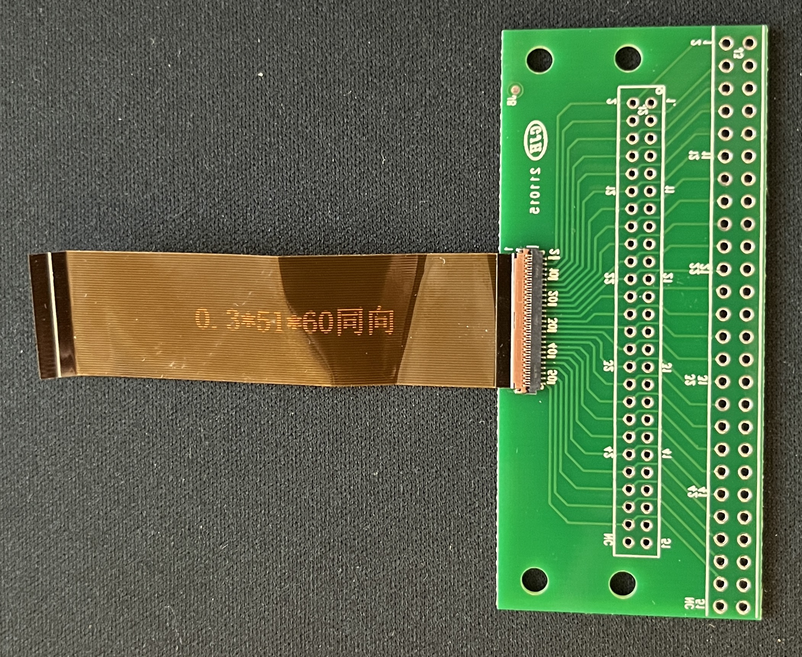
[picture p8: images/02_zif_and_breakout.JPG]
parts

- 2 breakout boards for all 51 pins 
- 2 60mm ZIF cables (a little bent, but should be fine)

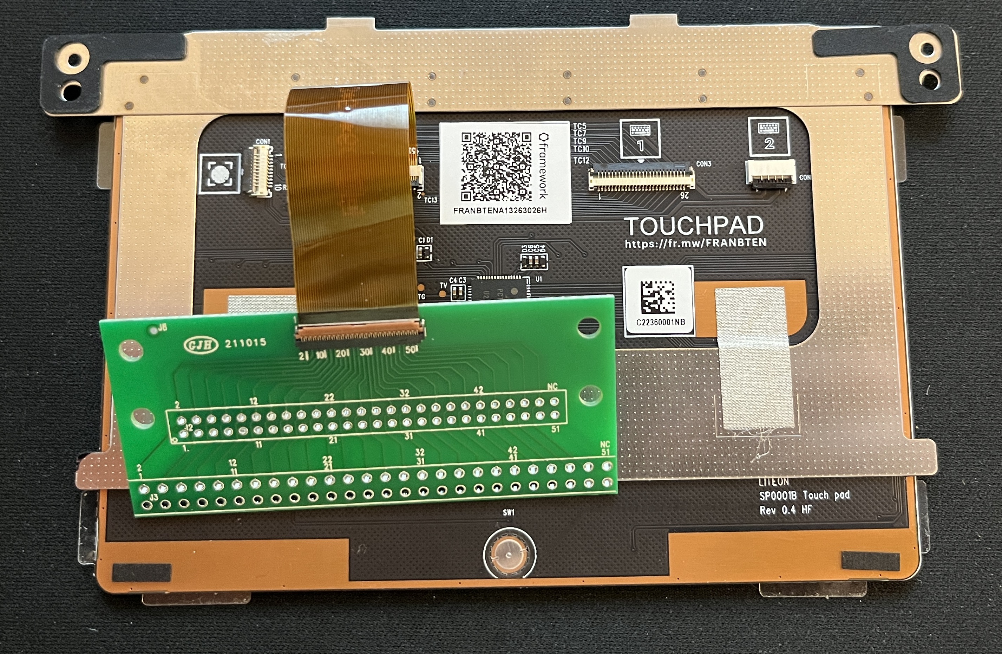
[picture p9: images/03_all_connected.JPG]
pieces1

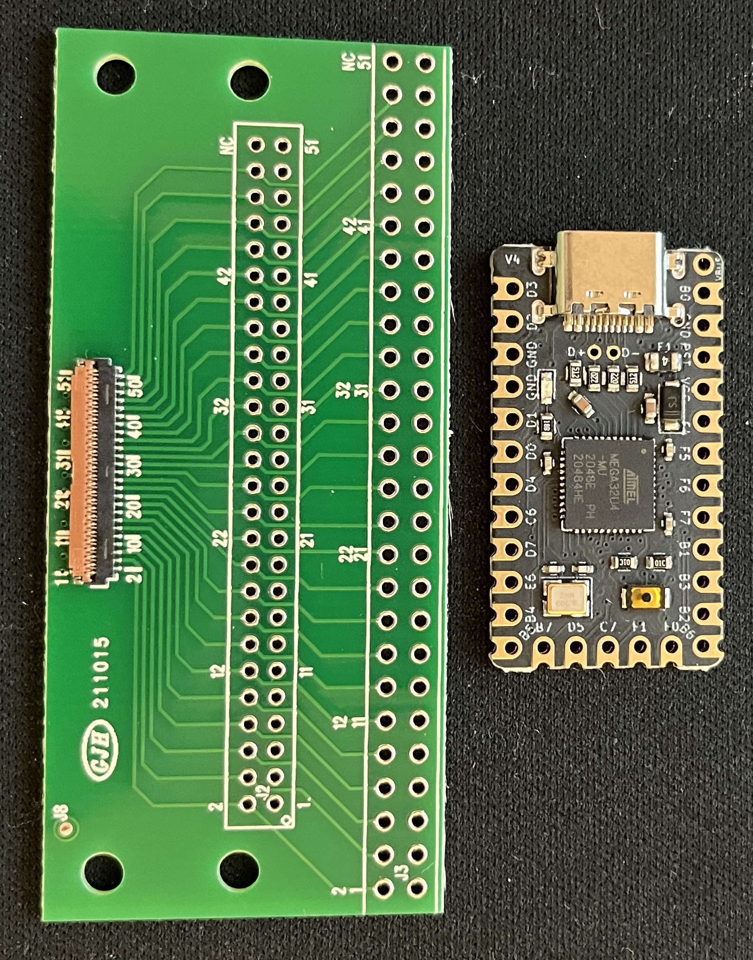
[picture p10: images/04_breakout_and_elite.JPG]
pieces2


I connected the board and the breakout board together. I'm not really sure how I am supposed to cram all of these into a compact package. 
Once I have the Elite C code set up and confirm the assembly is working, maybe I could design a smaller PCB with just the few pins I need for the touchpad. In the mean time, breadboard would be good enough for testing purposes. 

Will come back after I solder some pins on both the board and Elite C. 
w
## 2023/12/20
Soldered the parts. Pardon the sloppy solder job!

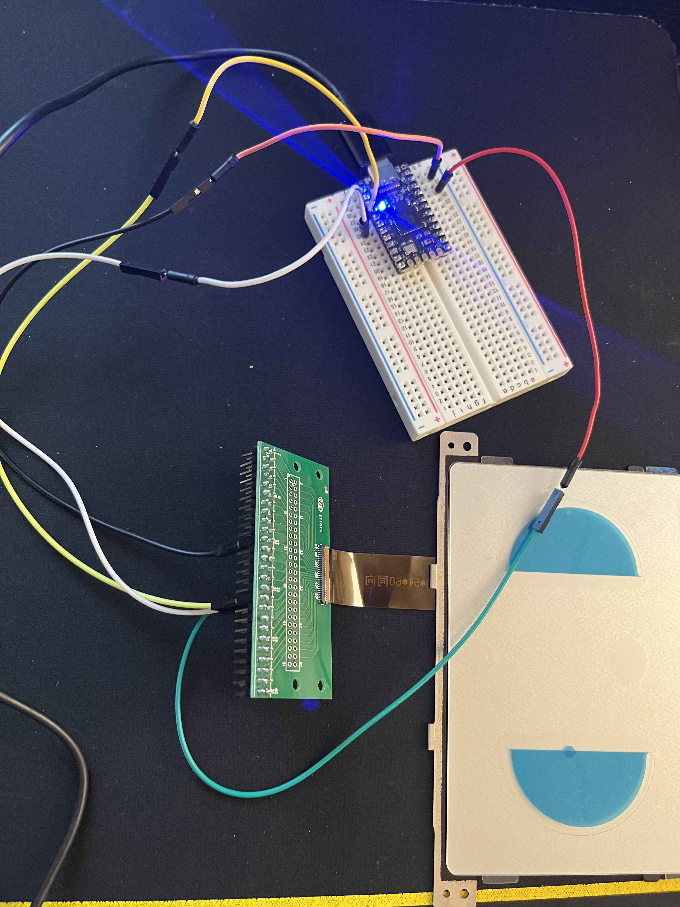
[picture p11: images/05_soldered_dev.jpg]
soldered


On a hindsight, I should have soldered the pins on the opposite side for the ZIF breakout board. Good thing I have extra. 

While all four pins "should" be connected correctly, my computer was unable to recognize Elite C when I plugged it via USB cable. Nothing showed up under PORT for any of the IDEs I tried! I think I'm missing some driver because QMK Toolbox could recognize Elite C just fine.

Need to figure out a way to work with ATMega32U4 next. Also my head hurts from all the soldering fume I inhaled earlier. 

## 2023/12/22

Turns out Elite-C is not compatible with Arduino IDE out of the box. Makes sense because this board was made for drop-in replacement for Pro Micro for keyboard folks. 

# 2023/12/24 
After digging around, I learned that it is possible to convert an Arduino-compatible board (like my Elite-C) to be recognized by Arduino IDE by flashing Arduino compatible bootloader. This can be achieved using special boards called programmer, but I could also use another Arduino to flash another board. Arduino IDE has built in example called "Arduino as ISP" that allows one Arduino to serve as programmer for another board (Following this official guide: [Arduino as ISP and Arduino Bootloaders](https://support.arduino.cc/hc/en-us/articles/4408887452434-Flash-USB-to-serial-firmware-in-DFU-mode))

Luckily I had an Arduino Uno from college, so I uploaded Arduino as ISP sketch and wired up my Elite C. After what felt like an eternity, Arduino Uno reported it had finished its job. My Elite C should now be recognized as Arduino Leonardo. Indeed, when I plugged in Elite C, it was immediately available in Arduino IDE. Now I should be able to write Arduino code and upload to my Elite C. 

I did a quick test to see if things are actually working by uploading the classic "Blink" sketch. Upload was seemingly successful, but the blue LED on the board was not blinking. After some frantic research, I found out that Elite-C does not have any onboard LED other than the Power indicator LED. Instead I decided to wire potentiometer and print out the results to the serial port. Thankfully I saw text printed to the console changing values as I turned the dial. Things were looking good.  

While I could have found a way to write code in C and directly upload whatever was compiled to the Elite C, I figured it would be much easier to use Arduino as I have 0 experience with directly interfacing with a microcontroller. 

# 2023/12/30

It's been a rough week, since I wasn't able to get the I2C connection working with the Arduino for a week. I made many mistakes along the way, such as connecting the ZIF cable backwards (!) and adding unnecessary pull up resistors. Using the [I2C scanner sketch](https://playground.arduino.cc/Main/I2cScanner/), I finally figured out the pin connections and the device ID of the touchpad. 

| Pin | Elite C | Breakout board |
| --- | --- | --- |
| SDA | D2 | 36 |
| SCL | D3 | 34 | 
| GND | GND | 33 |
| 5V | VCC | 40 |

And no need for any additional resistors. 

Reported I2C address is: 

```
I2C device found at address 0x2C  ! (44)
I2C device found at address 0x33  ! (51)
done
```

Not sure why there are two addresses reported though. 

Also just in case, the device address on an actual framework laptop is `/devices/pci0000:00/0000:00:15.3/i2c_designware.2/i2c-2/i2c-PIXA3854:00/0018:093A:0274.0004/input/input9`

Got a reading from address 0x2C, getting "37" whenever I  do anything

# 1/5/2024 
New year, but not much progress. Cannot quite figure out how to get a meaningful reading out of the touchpad without official data sheet available from the manufacturer. I did reach out to PixArt through their support portal, but my request for data sheet was declined. They said they just provided the IC, and Framework took  care of everything else such as firmware and the part development. 

Anyways tried dumping some data out of the registers. 

```
passionfruit@raspberrypi:~ $ i2cdetect -y 1
     0  1  2  3  4  5  6  7  8  9  a  b  c  d  e  f
00:                         -- -- -- -- -- -- -- --
10: -- -- -- -- -- -- -- -- -- -- -- -- -- -- -- --
20: -- -- -- -- -- -- -- -- -- -- -- -- 2c -- -- --
30: -- -- -- 33 -- -- -- -- -- -- -- -- -- -- -- --
40: -- -- -- -- -- -- -- -- -- -- -- -- -- -- -- --
50: -- -- -- -- -- -- -- -- -- -- -- -- -- -- -- --
60: -- -- -- -- -- -- -- -- -- -- -- -- -- -- -- --
70: -- -- -- -- -- -- -- --
```

Outputs of i2cdump on each device:

```
passionfruit@raspberrypi:~ $ i2cdump -y 1 0x2c
No size specified (using byte-data access)
     0  1  2  3  4  5  6  7  8  9  a  b  c  d  e  f    0123456789abcdef
00: 00 00 00 00 00 00 00 00 00 00 00 00 00 00 00 00    ................
10: 00 00 00 00 00 00 00 00 00 00 00 00 00 00 00 00    ................
20: 1e 06 00 00 00 00 00 00 00 00 00 00 00 00 00 00    ??..............
30: 00 00 00 00 00 00 00 00 00 00 00 00 00 00 00 00    ................
40: 00 00 00 00 00 00 00 00 00 00 00 00 00 00 00 00    ................
50: 00 00 00 00 00 00 00 00 00 00 00 00 00 00 00 00    ................
60: 00 00 00 00 00 00 00 00 00 00 00 00 00 00 00 00    ................
70: 00 00 00 00 00 00 00 00 00 00 00 00 00 00 00 00    ................
80: 00 00 00 00 00 00 00 00 00 00 00 00 00 00 00 00    ................
90: 00 00 00 00 00 00 00 00 00 00 00 00 00 00 00 00    ................
a0: 00 00 00 00 00 00 00 00 00 00 00 00 00 00 00 00    ................
b0: 00 00 00 00 00 00 00 00 00 00 00 00 00 00 00 00    ................
c0: 00 00 00 00 00 00 00 00 00 00 00 00 00 00 00 00    ................
d0: 00 00 00 00 00 00 00 00 00 00 00 00 00 00 00 00    ................
e0: 00 00 00 00 00 00 00 00 00 00 00 00 00 00 00 00    ................
f0: 00 00 00 00 00 00 00 00 00 00 00 00 00 00 00 00    ................
```

```
passionfruit@raspberrypi:~ $ i2cdump -y 1 0x33
No size specified (using byte-data access)
     0  1  2  3  4  5  6  7  8  9  a  b  c  d  e  f    0123456789abcdef
00: 00 00 00 00 00 00 00 00 00 00 01 00 00 00 1c 18    ..........?...??
10: 00 00 00 00 00 00 00 00 00 00 00 00 00 00 00 00    ................
20: 00 00 00 00 00 00 00 00 00 00 00 00 00 00 00 00    ................
30: 00 00 00 00 00 00 00 00 00 00 00 00 00 00 00 00    ................
40: 00 00 00 00 00 00 00 00 00 00 00 00 00 00 00 00    ................
50: 00 00 00 00 00 00 00 00 00 00 00 00 00 00 00 00    ................
60: 00 00 00 00 00 00 00 00 00 00 00 00 00 00 00 00    ................
70: 09 00 00 00 00 00 00 00 00 00 00 00 00 01 00 06    ?............?.?
80: 00 00 00 00 00 00 00 00 00 00 01 00 00 00 1c 18    ..........?...??
90: 00 00 00 00 00 00 00 00 00 00 00 00 00 00 00 00    ................
a0: 00 00 00 00 00 00 00 00 00 00 00 00 00 00 00 00    ................
b0: 00 00 00 00 00 00 00 00 00 00 00 00 00 00 00 00    ................
c0: 00 00 00 00 00 00 00 00 00 00 00 00 00 00 00 00    ................
d0: 00 00 00 00 00 00 00 00 00 00 00 00 00 00 00 00    ................
e0: 00 00 00 00 00 00 00 00 00 00 00 00 00 00 00 00    ................
f0: 09 00 00 00 00 00 00 00 00 00 00 00 00 01 00 06    ?............?.?
```

Values all stayed the same whether a finger was touching the pad or not.

```
passionfruit@raspberrypi:/sys/bus/i2c/devices $ i2cdump -y 1 0x33
No size specified (using byte-data access)
     0  1  2  3  4  5  6  7  8  9  a  b  c  d  e  f    0123456789abcdef
00: 00 00 00 00 00 00 00 00 00 00 01 00 00 00 1c 18    ..........?...??
10: 74 16 00 00 00 00 00 00 00 00 00 00 00 00 00 00    t?..............
20: 00 00 00 00 00 00 00 00 00 00 00 00 00 00 00 00    ................
30: 00 00 00 00 00 00 00 00 00 00 00 00 00 00 00 00    ................
40: 00 00 00 00 00 00 00 00 00 00 00 00 00 00 00 00    ................
50: 00 00 00 00 00 00 00 00 00 00 00 00 00 00 00 00    ................
60: 00 00 00 00 00 00 00 00 00 00 00 00 00 00 00 00    ................
70: c1 02 00 00 00 00 4d 01 00 00 00 00 00 01 00 06    ??....M?.....?.?
80: 00 00 00 00 00 00 00 00 00 00 01 00 00 00 1c 18    ..........?...??
90: 74 16 00 00 00 00 00 00 00 00 00 00 00 00 00 00    t?..............
a0: 00 00 00 00 00 00 00 00 00 00 00 00 00 00 00 00    ................
b0: 00 00 00 00 00 00 00 00 00 00 00 00 00 00 00 00    ................
c0: 00 00 00 00 00 00 00 00 00 00 00 00 00 00 00 00    ................
d0: 00 00 00 00 00 00 00 00 00 00 00 00 00 00 00 00    ................
e0: 00 00 00 00 00 00 00 00 00 00 00 00 00 00 00 00    ................
f0: c1 02 00 00 00 00 4d 01 00 00 00 00 00 01 00 06    ??....M?.....?.?
```

I noticed some changes in the values within the dump, but honestly I'm not sure how to proceed further. I did order the framework input cover thing mentioned earlier, so I will try and see if that leads me anywhere. At this point my only option seems to be  reverse engineering the thing. 

# 3/1/2024
Brought the set up to 2600 meet up, and got some help on how to dump things out of the register and format so that it prints out pretty. But we couldn't quite figure out how to get actual data read out from either of the registers. 

Still stuck?  

# 4/20/2024
Was scrolling hackaday and found an article titled [Human-Interfacing devices: HID over I2C](https://hackaday.com/2024/04/17/human-interfacing-devices-hid-over-i2c/). From 3 days ago. Clicked on it, and it's written by no one other than Arya, and contained whole lot of information on how to work with HID over I2C device. It turns out, I got the device ID 0x2c correct. All I had to do was read blocks out of the register 0x20 on this device on 0x2c. This was not possible through Raspberry Pi 3 I was using, as block read is not supported.

```
$ i2cdetect -F 1
Functionalities implemented by /dev/i2c-1:
I2C                              yes
SMBus Quick Command              yes
SMBus Send Byte                  yes
SMBus Receive Byte               yes
SMBus Write Byte                 yes
SMBus Read Byte                  yes
SMBus Write Word                 yes
SMBus Read Word                  yes
SMBus Process Call               yes
SMBus Block Write                yes
SMBus Block Read                 no
SMBus Block Process Call         no
SMBus PEC                        yes
I2C Block Write                  yes
I2C Block Read                   yes
```

Arya was using Circuit Python in the article, so I brought out Raspberry Pi Pico and installed Circuit Python. Only catch was that Pi Pico is 3.3V only, so I figured I could power the touchpad using the 5V pins from Raspberry Pi 3. 

However, when I loaded i2c, Circuit Python complained about missing pull up resistors.

```
import block
i2c = block.I2C() # This has to be something else, but forgot to write it down. 
```

That meant I had to use the power from the Raspberry Pi Pico, and then connect SDA/SCL with the power using resistors. Would touchpad work with 3.3V though? 

So I just pulled out the Elite C and wired out the breakout board, and ran the old script I had, which read a byte from 0x20 on I2c device 0x2c which always returns 37. 

Then it occurred to me, what if I read the entire block from 0x20 like Arya was doing? So I modified the script a little, and I actually was able to read meaningful data out of the touchpad.  

```
#include <Wire.h>  

#define ADDR 0x2C

void setup() {
  Wire.begin();  
  Serial.begin(115200);
  Serial.print("init");
}

void loop() {

  Wire.requestFrom(ADDR, 16);
  while(Wire.available()){
    char strBuf[4];
    byte c = Wire.read();
    sprintf(strBuf, "%02x", c);
    Serial.print(strBuf);
    Serial.print(" ");
  }

  Serial.print("\n");
  
  delay(1000); 
}
```

Some sample output
```
25 00 01 03 00 23 02 b4 01 00 00 00 00 00 00 00 
25 00 01 03 00 24 02 b4 01 00 00 00 00 00 00 00 
25 00 01 03 00 28 02 b4 01 03 01 48 03 dd 01 00 
25 00 01 03 00 2e 02 b4 01 03 01 49 03 dc 01 00 
25 00 01 03 00 35 02 b5 01 03 01 4c 03 dc 01 00 
25 00 01 03 00 fd 01 a7 01 03 01 07 03 dd 01 00 
25 00 01 03 00 47 02 8a 01 03 01 42 03 ec 01 00 
25 00 01 03 00 63 02 99 01 03 01 51 03 09 02 00 
25 00 01 03 00 1c 02 a8 01 03 01 0a 03 12 02 00 
25 00 01 03 00 e4 01 e7 01 03 01 0e 03 4d 02 00 
25 00 01 03 00 b4 01 0c 02 03 01 2b 03 5b 02 03 
00 00 01 01 00 f3 02 27 01 00 00 00 00 00 00 00 
00 00 01 01 00 f3 02 27 01 00 00 00 00 00 00 00 
00 00 01 01 00 f3 02 27 01 00 00 00 00 00 00 00 
00 00 01 01 00 f3 02 27 01 00 00 00 00 00 00 00 
00 00 01 01 00 f3 02 27 01 00 00 00 00 00 00 00 
00 00 01 01 00 f3 02 27 01 00 00 00 00 00 00 00 
```

Obviously, `00 00 01 01 00 f3 02 27 01 00 00 00 00 00 00 00` is the "idle" state.

I would need to read more on the spec, but it looks like these values are the HID descriptor, so I should be able to further decode what this byte soup means. Regardless, a huge progress. 

## Single finger
```
25 00 01 03 00 a1 01 95 01 03 01 bb 02 e5 01 03 
25 00 01 03 00 a5 01 8d 01 03 01 f1 02 ba 01 03 
25 00 01 03 00 de 01 63 01 03 01 31 03 93 01 03 
25 00 01 01 00 de 01 63 01 01 01 31 03 93 01 01 
00 00 01 01 00 de 01 63 01 01 01 31 03 93 01 01 
00 00 01 01 00 de 01 63 01 01 01 31 03 93 01 01 
25 00 01 03 00 a3 02 92 00 00 00 00 00 00 00 00 
25 00 01 03 00 a3 02 92 00 00 00 00 00 00 00 00 
25 00 01 03 00 a3 02 92 00 00 00 00 00 00 00 00 
25 00 01 03 00 a3 02 92 00 00 00 00 00 00 00 00 
25 00 01 03 00 a3 02 a4 00 00 00 00 00 00 00 00 
25 00 01 03 00 a9 02 3f 01 00 00 00 00 00 00 00 
25 00 01 03 00 b5 02 f8 01 00 00 00 00 00 00 00 
25 00 01 01 00 b5 02 f8 01 00 00 00 00 00 00 00 
25 00 01 03 01 ea 02 0d 00 00 00 00 00 00 00 00 
25 00 01 03 01 0e 03 12 01 00 00 00 00 00 00 00 
25 00 01 01 01 0e 03 12 01 00 00 00 00 00 00 00 
25 00 01 03 00 43 03 e6 00 00 00 00 00 00 00 00 
25 00 01 01 00 43 03 e6 00 00 00 00 00 00 00 00 
25 00 01 03 01 e2 03 01 00 00 00 00 00 00 00 00 
25 00 01 03 01 e1 03 f0 00 00 00 00 00 00 00 00 
25 00 01 01 01 e1 03 f0 00 00 00 00 00 00 00 00 
25 00 01 03 00 84 03 2c 00 00 00 00 00 00 00 00
```

## Two fingers
```
00 00 01 01 00 7f 03 9c 01 00 00 00 00 00 00 00 
00 00 01 01 00 7f 03 9c 01 00 00 00 00 00 00 00 
25 00 01 03 00 51 02 4d 00 00 00 00 00 00 00 00 
25 00 01 03 00 51 02 4d 00 00 00 00 00 00 00 00 
25 00 01 03 00 51 02 4d 00 00 00 00 00 00 00 00 
25 00 01 03 00 51 02 4d 00 03 01 71 03 94 00 00 
25 00 01 03 00 67 02 a0 00 03 01 87 03 e9 00 00 
25 00 01 01 00 67 02 a0 00 01 01 87 03 e9 00 00 
25 00 01 03 02 3b 02 10 00 03 03 c1 03 39 00 00 
25 00 01 03 02 69 02 fd 00 03 03 d1 03 3b 01 00 
25 00 01 01 02 69 02 fd 00 01 03 d1 03 3b 01 00 
25 00 01 03 00 1d 02 6f 02 03 01 46 03 cd 02 00 
25 00 01 03 00 35 02 e9 01 03 01 70 03 3a 02 00 
25 00 01 03 00 22 02 42 01 01 01 70 03 3a 02 00 
25 00 01 01 00 22 02 42 01 00 00 00 00 00 00 00 
25 00 01 03 00 00 02 ae 00 03 01 70 03 dd 00 00 
25 00 01 03 00 00 02 af 00 03 01 70 03 de 00 00 
```

## Three fingers 
```
00 00 01 01 00 03 02 b7 00 01 01 71 03 e5 00 00 
00 00 01 01 00 03 02 b7 00 01 01 71 03 e5 00 00 
25 00 01 03 00 c0 02 0a 00 03 01 9a 01 76 00 00 
25 00 01 03 00 c0 02 0a 00 03 01 9a 01 76 00 03 
25 00 01 03 00 c0 02 0a 00 03 01 9a 01 76 00 03 
25 00 01 03 00 c0 02 0a 00 03 01 9a 01 76 00 03 
25 00 01 01 00 c0 02 0a 00 01 01 9a 01 76 00 01 
25 00 01 03 00 cf 00 99 00 00 00 00 00 00 00 00 
25 00 01 03 00 cf 00 99 00 00 00 00 00 00 00 00 
25 00 01 03 00 cf 00 99 00 03 01 e8 01 0a 00 00 
25 00 01 03 00 cf 00 99 00 03 01 e8 01 0a 00 00 
25 00 01 01 00 cf 00 99 00 01 01 e8 01 0a 00 00 
25 00 01 03 00 d4 01 d9 00 00 00 00 00 00 00 00 
25 00 01 03 00 d4 01 d9 00 03 01 54 03 30 01 03 
25 00 01 03 00 d4 01 d9 00 03 01 54 03 30 01 03 
25 00 01 03 00 d4 01 d9 00 03 01 54 03 30 01 03 
25 00 01 01 00 d4 01 d9 00 01 01 54 03 30 01 01 
00 00 01 01 00 d4 01 d9 00 01 01 54 03 30 01 01 
00 00 01 01 00 d4 01 d9 00 01 01 54 03 30 01 01 
00 00 01 01 00 d4 01 d9 00 01 01 54 03 30 01 01
```

Apparently something is not right with how I'm printing the bytes. Should tweak the code until I get the right HID descriptor out.

# Sometime in September
Learned about something called FT260 mentioned in [Framework Forum](https://community.frame.work/t/touchpad-with-2-buttons-instead-of-clickpad/36343/18), and ordered [UMFT260EV1A](https://ftdichip.com/products/umft260ev1a/)
Connected it up but wasn't able to do much with it. Honestly not sure how this comes into the picture. Would need more research 

| Name | FT 260 | Dev board | Touchpad | 
|---|---|---|---|
| SCL | DIO5 | IO0 | 34 | 
| SDA | DIO6 | IO1 | 36 |
| INT | DIO8 | IO3 | 35 |
| 5V | - | - | 40 | 
| GND | - | - | 33 |

# 10/3/2024 

Been using Micropython on the Raspberry Pi Pico to do the I2C over HID circus. 

Few things I learned in the past few days:
* Touchpad alone can run on 3v3.
* Micropython 1.23 now has USB device support which could be used for this (as was mentioned in Arya's article)
* I have been able to read "something" out of the touchpad before. I'm still getting the same data, but I was not reading the full data.
  * 25 in the beginning meant 0x25 = 37, so I should have been reading 37 bytes.
* The data extracted from I2C has some kind of pattern. Not sure what the details are, need more probing
* data from I2C is probably not the HID Descriptor that could be readily used; this data has to be translated into Mouse HID Descriptor again and then sent to the host

table

# 10/4/2024 

Some more observations. Each output from I2C is something like this: 

```
03 00 3b 00 15 00 03 01 f3 04 37 00 03 02 5d 00 30 03 03 03 de 04 1b 03 00 00 00 00 00 00 04 00 21 27
```

First Finger reported `3b 00 15 00`. In these 4 bytes, first two correspond to the X coordinate and the latter two correspond to the Y coordinate. 
That explains why each fingers have 2+4 bytes repeated.

So I think these 2+4 bytes mean something like this: 

| ??? | finger index (0 based)| X First Byte | X Second Byte | Y First Byte | Y Second Byte| 
|---|---|---|---|---|---|
|03 | 01 | f3 | 04 | 37 | 00 |

These kind of align with what is said in PCT1336QN's manual, though that one has way too many more registors than what I'm currently reading out of PCT3854QR. 

```python
# Scan for connected I2C devices  
import machine

SDA_PIN = machine.Pin(4)
SCL_PIN = machine.Pin(5)
i2c = machine.I2C(0, sda=SDA_PIN, scl=SCL_PIN, freq=500000)

TOUCHPAD_ADDR = 0x2c
REPORT_ID = 0x01 

def helper_function(abc):
    return ([abc[i:i+2] for i in range(0, len(abc), 2)])

def helper_function_to_int(myList):
    k = [int(x, 16) for x in myList]
    v = ["{:03d}".format(x) for x in k]
    return  [str(x) for x in v]

def runner():
    while True:
        try:
            l = i2c.readfrom(TOUCHPAD_ADDR, 1)[0]
            if l:
                d = i2c.readfrom(TOUCHPAD_ADDR, l)
                if d[2] != REPORT_ID:
                    print("WARNING")
                    print(l, d)
                else:
                    d = d[3:]
                    formatted = helper_function(d.hex())
                    output = helper_function_to_int(formatted)
                    print(" ".join(output))
                    
        except OSError:
            print("Nothing burger")

runner()
```

I'm using above code to print out the data to the console. In hopes of plotting out the data, I'm formatting the byte data to 3 digit int. 
I attempted plotting the X Y coordinates (using the formula `=A + 255*B`) and got a nice line out of it.

This still feels like raw data though. This chip is supposed to give HID over I2C, so I don't think I should be getting the raw finger coordinate data. Shouldn't this chip interpret all these finger movements and return some HID descriptor instead? 

# 10/8/2024

While I have some mystery values in each row, I at least have the coordinates for the 5 fingers. Still cannot quite figure out why I'm not reading the HID descriptor directly from the HID, but I'm going to try using this raw data to move mouse cursor around. 

From rough calculations, the X dimension ranges from `0 to 0x0539 = 256*5+57 = 1337` and Y dimension ranges from 0 to `0x36C = 256*3 + 108 = 876`

```
001 000 **057 005** 046 003
003 000 231 004 **108 003**
```

These values actually match the values in Arya's descriptor ([HID_USAGE_DESKTOP_X LOGICAL MAX = 1337](https://github.com/0xAryaCAFE/spicy-micropython/blob/3810a95b423668ce8a7be2f6eb615eec5d33fedd/ports/rp2/tusb_port.c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) and [HID_USAGE_DESKTOP_Y LOGICAL MAX = 876](https://github.com/0xAryaCAFE/spicy-micropython/blob/3810a95b423668ce8a7be2f6eb615eec5d33fedd/ports/rp2/tusb_port.c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))

I can also dump the descriptor from my framework laptop and compare it with the data I am reading from I2C as well. 

As of now, the first byte which has values 0x00 to 0x03 seem to be related to palm rejection or some sort of indication whether this is a legitimate touch or accidental. 

When I have one point contact, I see the byte has value 0x03. When I smear my fingers around, I can see the value fluctuating. 

| palm rejection (??) | finger index (0 based)| X First Byte | X Second Byte | Y First Byte | Y Second Byte| 
|---|---|---|---|---|---|
|03 | 01 | f3 | 04 | 37 | 00 |

As for the last 4 bytes, I realized the last byte is some kind of ID that increments by 1 every time I read a row. It loops from 0x00 to 0xff, and when the device starts, it initiates from 0. 

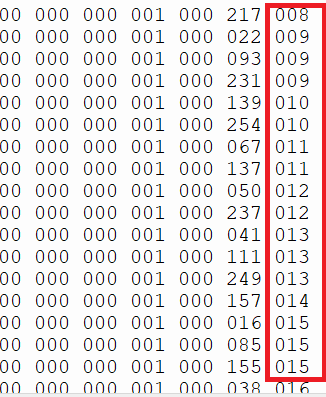
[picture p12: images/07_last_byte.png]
last_byte


| number of fingers | ??? but always 0x00 | ??? | ID % 255 |
| --- | --- | --- | --- |
|05 | 00 | e2 | d5 |

# 10/11/2024

How would interrupt work for this device? Does it mean there is a signal coming out of it when interrupt is sent? 
So can I just hook it up to a GPIO and listen to it?

Some things to consider... but can definitely wait after translating finger signal to descriptor is done 

mystery penultimate byte also ranges from 0 to 255, so it does use all the values. 

Some kind of bit operation to quickly process touch registers & extract coordinates? 

C or python?

Resources: 
- [framework embedded controller i2c_hid.h (from chromebook)](https://github.com/FrameworkComputer/EmbeddedController/blob/hx20-hx30/include/i2c_hid.h)
- [framework embedded controller i2c_hid_touchpad.h (from  chromebook)](https://github.com/FrameworkComputer/EmbeddedController/blob/hx20-hx30/include/i2c_hid_touchpad.h)
- [framework embedded controller i2c_hid_touchpad.c (from  chromebook)](https://github.com/FrameworkComputer/EmbeddedController/blob/hx20-hx30/common/i2c_hid_touchpad.c)
- [synaptics touchpad driver - SPI to HID](https://github.com/delingren/synaptics_touchpad/blob/main/touchpad.ino#L368)
- [nrf52-i2c-hid demo (Adafruit feather)](https://github.com/NordicPlayground/nrf52-i2c-hid-demo/blob/master/nrf52-i2c-hid-demo/main.c)
- [micropython USB hid-device-mouse example](https://github.com/micropython/micropython-lib/blob/master/micropython/usb/usb-device-mouse/usb/device/mouse.py)

# 10/16/2024

I was rereading everything and I realized I was not reading from a specific register. 
From what I could gather, HID over I2C is supposed to return HID descriptor directly over I2C interface. So whatever I was reading was cool in a sense that it gives me x/y coordinates, that was incorrect.

With the lack of documentation, I figured I could just scan the I2C device over some range and see if I could get something out. 

I wrote a little code to dump 64 bytes from each register on 0x2C starting from 0 to 255

```
def helper_function_to_int(myList):
    k = [int(x, 16) for x in myList]
    v = ["{:03d}".format(x) for x in k]
    return  [str(x) for x in v]

def brute_force():
    for i in range(0, 256):
        l = i2c.readfrom_mem(TOUCHPAD_ADDR, i, 64)
        print(i, " ".join(helper_function(l.hex())))

```

and just scrolled through each nonsense lines, and then something caught my eyes. 

```
24 00 00 00 01 af 02 21 00 24 00 25 00 25 00 00 00 22 00 23 00 3a 09 74 02 04 07 00 00 00 00 00 00 00 03 00 91 f5 00 00 00 00 00 00 00 00 00 00 00 00 00 00 00 00 00 00 00 00 00 00 00 00 00 00 00
25 00 00 00 01 af 02 21 00 24 00 25 00 25 00 00 00 22 00 23 00 3a 09 74 02 04 07 00 00 00 00 00 00 00 03 00 91 f5 00 00 00 00 00 00 00 00 00 00 00 00 00 00 00 00 00 00 00 00 00 00 00 00 00 00 00
26 00 00 00 01 af 02 21 00 24 00 25 00 25 00 00 00 22 00 23 00 3a 09 74 02 04 07 00 00 00 00 00 00 00 03 00 91 f5 00 00 00 00 00 00 00 00 00 00 00 00 00 00 00 00 00 00 00 00 00 00 00 00 00 00 00
27 00 00 00 01 af 02 21 00 24 00 25 00 25 00 00 00 22 00 23 00 3a 09 74 02 04 07 00 00 00 00 00 00 00 03 00 91 f5 00 00 00 00 00 00 00 00 00 00 00 00 00 00 00 00 00 00 00 00 00 00 00 00 00 00 00
28 00 00 00 01 af 02 21 00 24 00 25 00 25 00 00 00 22 00 23 00 3a 09 74 02 04 07 00 00 00 00 00 00 00 03 00 91 f5 00 00 00 00 00 00 00 00 00 00 00 00 00 00 00 00 00 00 00 00 00 00 00 00 00 00 00
29 00 00 00 01 af 02 21 00 24 00 25 00 25 00 00 00 22 00 23 00 3a 09 74 02 04 07 00 00 00 00 00 00 00 03 00 91 f5 00 00 00 00 00 00 00 00 00 00 00 00 00 00 00 00 00 00 00 00 00 00 00 00 00 00 00
30 00 00 00 01 af 02 21 00 24 00 25 00 25 00 00 00 22 00 23 00 3a 09 74 02 04 07 00 00 00 00 00 00 00 03 00 91 f5 00 00 00 00 00 00 00 00 00 00 00 00 00 00 00 00 00 00 00 00 00 00 00 00 00 00 00
31 00 00 00 01 af 02 21 00 24 00 25 00 25 00 00 00 22 00 23 00 3a 09 74 02 04 07 00 00 00 00 00 00 00 03 00 91 f5 00 00 00 00 00 00 00 00 00 00 00 00 00 00 00 00 00 00 00 00 00 00 00 00 00 00 00
32 1e 00 00 01 af 02 21 00 24 00 25 00 25 00 00 00 22 00 23 00 3a 09 74 02 04 07 00 00 00 00 00 00 00 00 00 00 00 00 00 00 00 00 00 00 00 00 00 00 00 00 00 00 00 00 00 00 00 00 00 00 00 00 00 00
33 05 01 09 02 a1 01 85 02 05 01 09 01 a1 00 05 09 19 01 29 02 15 00 25 01 75 01 95 02 81 02 05 0d 09 32 75 01 95 01 81 02 75 05 95 01 81 03 05 01 75 10 95 01 35 00 45 00 16 00 80 26 ff 7f 09 30
34 00 00 00 01 af 02 21 00 24 00 25 00 25 00 00 00 22 00 23 00 3a 09 74 02 04 07 00 00 00 00 00 00 00 03 00 91 f5 00 00 00 00 00 00 00 00 00 00 00 00 00 00 00 00 00 00 00 00 00 00 00 00 00 00 00
35 00 00 00 01 af 02 21 00 24 00 25 00 25 00 00 00 22 00 23 00 3a 09 74 02 04 07 00 00 00 00 00 00 00 03 00 91 f5 00 00 00 00 00 00 00 00 00 00 00 00 00 00 00 00 00 00 00 00 00 00 00 00 00 00 00
36 00 00 00 01 af 02 21 00 24 00 25 00 25 00 00 00 22 00 23 00 3a 09 74 02 04 07 00 00 00 00 00 00 00 03 00 91 f5 00 00 00 00 00 00 00 00 00 00 00 00 00 00 00 00 00 00 00 00 00 00 00 00 00 00 00
37 00 00 00 01 af 02 21 00 24 00 25 00 25 00 00 00 22 00 23 00 3a 09 74 02 04 07 00 00 00 00 00 00 00 03 00 91 f5 00 00 00 00 00 00 00 00 00 00 00 00 00 00 00 00 00 00 00 00 00 00 00 00 00 00 00
38 00 00 00 01 af 02 21 00 24 00 25 00 25 00 00 00 22 00 23 00 3a 09 74 02 04 07 00 00 00 00 00 00 00 03 00 91 f5 00 00 00 00 00 00 00 00 00 00 00 00 00 00 00 00 00 00 00 00 00 00 00 00 00 00 00
```

line 33 (0x21) had something that awfully resembles HID Descriptor. And indeed, it was correct:

```
0x05, 0x01,        // Usage Page (Generic Desktop Ctrls)
0x09, 0x02,        // Usage (Mouse)
0xA1, 0x01,        // Collection (Application)
0x85, 0x02,        //   Report ID (2)
0x05, 0x01,        //   Usage Page (Generic Desktop Ctrls)
0x09, 0x01,        //   Usage (Pointer)
0xA1, 0x00,        //   Collection (Physical)
0x05, 0x09,        //     Usage Page (Button)
0x19, 0x01,        //     Usage Minimum (0x01)
0x29, 0x02,        //     Usage Maximum (0x02)
0x15, 0x00,        //     Logical Minimum (0)
0x25, 0x01,        //     Logical Maximum (1)
0x75, 0x01,        //     Report Size (1)
0x95, 0x02,        //     Report Count (2)
0x81, 0x02,        //     Input (Data,Var,Abs,No Wrap,Linear,Preferred State,No Null Position)
0x05, 0x0D,        //     Usage Page (Digitizer)
0x09, 0x32,        //     Usage (In Range)
0x75, 0x01,        //     Report Size (1)
0x95, 0x01,        //     Report Count (1)
0x81, 0x02,        //     Input (Data,Var,Abs,No Wrap,Linear,Preferred State,No Null Position)
0x75, 0x05,        //     Report Size (5)
0x95, 0x01,        //     Report Count (1)
0x81, 0x03,        //     Input (Const,Var,Abs,No Wrap,Linear,Preferred State,No Null Position)
0x05, 0x01,        //     Usage Page (Generic Desktop Ctrls)
0x75, 0x10,        //     Report Size (16)
0x95, 0x01,        //     Report Count (1)
0x35, 0x00,        //     Physical Minimum (0)
0x45, 0x00,        //     Physical Maximum (0)
0x16, 0x00, 0x80,  //     Logical Minimum (-32768)
0x26, 0xFF, 0x7F,  //     Logical Maximum (32767)
0x09, 0x30,        //     Usage (X)

// 64 bytes

```

😊

0x21 on 0x2C to retrieve the descriptor. 

Full descriptor below: 

```
0x05, 0x01,        // Usage Page (Generic Desktop Ctrls)
0x09, 0x02,        // Usage (Mouse)
0xA1, 0x01,        // Collection (Application)
0x85, 0x02,        //   Report ID (2)
0x05, 0x01,        //   Usage Page (Generic Desktop Ctrls)
0x09, 0x01,        //   Usage (Pointer)
0xA1, 0x00,        //   Collection (Physical)
0x05, 0x09,        //     Usage Page (Button)
0x19, 0x01,        //     Usage Minimum (0x01)
0x29, 0x02,        //     Usage Maximum (0x02)
0x15, 0x00,        //     Logical Minimum (0)
0x25, 0x01,        //     Logical Maximum (1)
0x75, 0x01,        //     Report Size (1)
0x95, 0x02,        //     Report Count (2)
0x81, 0x02,        //     Input (Data,Var,Abs,No Wrap,Linear,Preferred State,No Null Position)
0x05, 0x0D,        //     Usage Page (Digitizer)
0x09, 0x32,        //     Usage (In Range)
0x75, 0x01,        //     Report Size (1)
0x95, 0x01,        //     Report Count (1)
0x81, 0x02,        //     Input (Data,Var,Abs,No Wrap,Linear,Preferred State,No Null Position)
0x75, 0x05,        //     Report Size (5)
0x95, 0x01,        //     Report Count (1)
0x81, 0x03,        //     Input (Const,Var,Abs,No Wrap,Linear,Preferred State,No Null Position)
0x05, 0x01,        //     Usage Page (Generic Desktop Ctrls)
0x75, 0x10,        //     Report Size (16)
0x95, 0x01,        //     Report Count (1)
0x35, 0x00,        //     Physical Minimum (0)
0x45, 0x00,        //     Physical Maximum (0)
0x16, 0x00, 0x80,  //     Logical Minimum (-32768)
0x26, 0xFF, 0x7F,  //     Logical Maximum (32767)
0x09, 0x30,        //     Usage (X)
0x81, 0x26,        //     Input (Data,Var,Rel,No Wrap,Linear,No Preferred State,No Null Position)
0x16, 0x00, 0x80,  //     Logical Minimum (-32768)
0x26, 0xFF, 0x7F,  //     Logical Maximum (32767)
0x09, 0x31,        //     Usage (Y)
0x81, 0x26,        //     Input (Data,Var,Rel,No Wrap,Linear,No Preferred State,No Null Position)
0xC0,              //   End Collection
0xC0,              // End Collection
0x05, 0x0D,        // Usage Page (Digitizer)
0x09, 0x05,        // Usage (Touch Pad)
0xA1, 0x01,        // Collection (Application)
0x85, 0x01,        //   Report ID (1)
0x05, 0x0D,        //   Usage Page (Digitizer)
0x09, 0x22,        //   Usage (Finger)
0xA1, 0x02,        //   Collection (Logical)
0x09, 0x47,        //     Usage (0x47)
0x09, 0x42,        //     Usage (Tip Switch)
0x15, 0x00,        //     Logical Minimum (0)
0x25, 0x01,        //     Logical Maximum (1)
0x75, 0x01,        //     Report Size (1)
0x95, 0x02,        //     Report Count (2)
0x81, 0x02,        //     Input (Data,Var,Abs,No Wrap,Linear,Preferred State,No Null Position)
0x95, 0x06,        //     Report Count (6)
0x81, 0x03,        //     Input (Const,Var,Abs,No Wrap,Linear,Preferred State,No Null Position)
0x09, 0x51,        //     Usage (0x51)
0x25, 0x0F,        //     Logical Maximum (15)
0x75, 0x08,        //     Report Size (8)
0x95, 0x01,        //     Report Count (1)
0x81, 0x02,        //     Input (Data,Var,Abs,No Wrap,Linear,Preferred State,No Null Position)
0x05, 0x01,        //     Usage Page (Generic Desktop Ctrls)
0x09, 0x30,        //     Usage (X)
0x75, 0x10,        //     Report Size (16)
0x55, 0x0E,        //     Unit Exponent (-2)
0x65, 0x11,        //     Unit (System: SI Linear, Length: Centimeter)
0x35, 0x00,        //     Physical Minimum (0)
0x46, 0x5A, 0x04,  //     Physical Maximum (1114)
0x27, 0x39, 0x05, 0x00, 0x00,  //     Logical Maximum (1336)
0x81, 0x02,        //     Input (Data,Var,Abs,No Wrap,Linear,Preferred State,No Null Position)
0x09, 0x31,        //     Usage (Y)
0x46, 0xDA, 0x02,  //     Physical Maximum (730)
0x27, 0x6C, 0x03, 0x00, 0x00,  //     Logical Maximum (875)
0x81, 0x02,        //     Input (Data,Var,Abs,No Wrap,Linear,Preferred State,No Null Position)
0xC0,              //   End Collection
0x05, 0x0D,        //   Usage Page (Digitizer)
0x09, 0x22,        //   Usage (Finger)
0xA1, 0x02,        //   Collection (Logical)
0x09, 0x47,        //     Usage (0x47)
0x09, 0x42,        //     Usage (Tip Switch)
0x15, 0x00,        //     Logical Minimum (0)
0x25, 0x01,        //     Logical Maximum (1)
0x75, 0x01,        //     Report Size (1)
0x95, 0x02,        //     Report Count (2)
0x81, 0x02,        //     Input (Data,Var,Abs,No Wrap,Linear,Preferred State,No Null Position)
0x95, 0x06,        //     Report Count (6)
0x81, 0x03,        //     Input (Const,Var,Abs,No Wrap,Linear,Preferred State,No Null Position)
0x09, 0x51,        //     Usage (0x51)
0x25, 0x0F,        //     Logical Maximum (15)
0x75, 0x08,        //     Report Size (8)
0x95, 0x01,        //     Report Count (1)
0x81, 0x02,        //     Input (Data,Var,Abs,No Wrap,Linear,Preferred State,No Null Position)
0x05, 0x01,        //     Usage Page (Generic Desktop Ctrls)
0x09, 0x30,        //     Usage (X)
0x75, 0x10,        //     Report Size (16)
0x55, 0x0E,        //     Unit Exponent (-2)
0x65, 0x11,        //     Unit (System: SI Linear, Length: Centimeter)
0x35, 0x00,        //     Physical Minimum (0)
0x46, 0x5A, 0x04,  //     Physical Maximum (1114)
0x27, 0x39, 0x05, 0x00, 0x00,  //     Logical Maximum (1336)
0x81, 0x02,        //     Input (Data,Var,Abs,No Wrap,Linear,Preferred State,No Null Position)
0x09, 0x31,        //     Usage (Y)
0x46, 0xDA, 0x02,  //     Physical Maximum (730)
0x27, 0x6C, 0x03, 0x00, 0x00,  //     Logical Maximum (875)
0x81, 0x02,        //     Input (Data,Var,Abs,No Wrap,Linear,Preferred State,No Null Position)
0xC0,              //   End Collection
0x05, 0x0D,        //   Usage Page (Digitizer)
0x09, 0x22,        //   Usage (Finger)
0xA1, 0x02,        //   Collection (Logical)
0x09, 0x47,        //     Usage (0x47)
0x09, 0x42,        //     Usage (Tip Switch)
0x15, 0x00,        //     Logical Minimum (0)
0x25, 0x01,        //     Logical Maximum (1)
0x75, 0x01,        //     Report Size (1)
0x95, 0x02,        //     Report Count (2)
0x81, 0x02,        //     Input (Data,Var,Abs,No Wrap,Linear,Preferred State,No Null Position)
0x95, 0x06,        //     Report Count (6)
0x81, 0x03,        //     Input (Const,Var,Abs,No Wrap,Linear,Preferred State,No Null Position)
0x09, 0x51,        //     Usage (0x51)
0x25, 0x0F,        //     Logical Maximum (15)
0x75, 0x08,        //     Report Size (8)
0x95, 0x01,        //     Report Count (1)
0x81, 0x02,        //     Input (Data,Var,Abs,No Wrap,Linear,Preferred State,No Null Position)
0x05, 0x01,        //     Usage Page (Generic Desktop Ctrls)
0x09, 0x30,        //     Usage (X)
0x75, 0x10,        //     Report Size (16)
0x55, 0x0E,        //     Unit Exponent (-2)
0x65, 0x11,        //     Unit (System: SI Linear, Length: Centimeter)
0x35, 0x00,        //     Physical Minimum (0)
0x46, 0x5A, 0x04,  //     Physical Maximum (1114)
0x27, 0x39, 0x05, 0x00, 0x00,  //     Logical Maximum (1336)
0x81, 0x02,        //     Input (Data,Var,Abs,No Wrap,Linear,Preferred State,No Null Position)
0x09, 0x31,        //     Usage (Y)
0x46, 0xDA, 0x02,  //     Physical Maximum (730)
0x27, 0x6C, 0x03, 0x00, 0x00,  //     Logical Maximum (875)
0x81, 0x02,        //     Input (Data,Var,Abs,No Wrap,Linear,Preferred State,No Null Position)
0xC0,              //   End Collection
0x05, 0x0D,        //   Usage Page (Digitizer)
0x09, 0x22,        //   Usage (Finger)
0xA1, 0x02,        //   Collection (Logical)
0x09, 0x47,        //     Usage (0x47)
0x09, 0x42,        //     Usage (Tip Switch)
0x15, 0x00,        //     Logical Minimum (0)
0x25, 0x01,        //     Logical Maximum (1)
0x75, 0x01,        //     Report Size (1)
0x95, 0x02,        //     Report Count (2)
0x81, 0x02,        //     Input (Data,Var,Abs,No Wrap,Linear,Preferred State,No Null Position)
0x95, 0x06,        //     Report Count (6)
0x81, 0x03,        //     Input (Const,Var,Abs,No Wrap,Linear,Preferred State,No Null Position)
0x09, 0x51,        //     Usage (0x51)
0x25, 0x0F,        //     Logical Maximum (15)
0x75, 0x08,        //     Report Size (8)
0x95, 0x01,        //     Report Count (1)
0x81, 0x02,        //     Input (Data,Var,Abs,No Wrap,Linear,Preferred State,No Null Position)
0x05, 0x01,        //     Usage Page (Generic Desktop Ctrls)
0x09, 0x30,        //     Usage (X)
0x75, 0x10,        //     Report Size (16)
0x55, 0x0E,        //     Unit Exponent (-2)
0x65, 0x11,        //     Unit (System: SI Linear, Length: Centimeter)
0x35, 0x00,        //     Physical Minimum (0)
0x46, 0x5A, 0x04,  //     Physical Maximum (1114)
0x27, 0x39, 0x05, 0x00, 0x00,  //     Logical Maximum (1336)
0x81, 0x02,        //     Input (Data,Var,Abs,No Wrap,Linear,Preferred State,No Null Position)
0x09, 0x31,        //     Usage (Y)
0x46, 0xDA, 0x02,  //     Physical Maximum (730)
0x27, 0x6C, 0x03, 0x00, 0x00,  //     Logical Maximum (875)
0x81, 0x02,        //     Input (Data,Var,Abs,No Wrap,Linear,Preferred State,No Null Position)
0xC0,              //   End Collection
0x05, 0x0D,        //   Usage Page (Digitizer)
0x09, 0x22,        //   Usage (Finger)
0xA1, 0x02,        //   Collection (Logical)
0x09, 0x47,        //     Usage (0x47)
0x09, 0x42,        //     Usage (Tip Switch)
0x15, 0x00,        //     Logical Minimum (0)
0x25, 0x01,        //     Logical Maximum (1)
0x75, 0x01,        //     Report Size (1)
0x95, 0x02,        //     Report Count (2)
0x81, 0x02,        //     Input (Data,Var,Abs,No Wrap,Linear,Preferred State,No Null Position)
0x95, 0x06,        //     Report Count (6)
0x81, 0x03,        //     Input (Const,Var,Abs,No Wrap,Linear,Preferred State,No Null Position)
0x09, 0x51,        //     Usage (0x51)
0x25, 0x0F,        //     Logical Maximum (15)
0x75, 0x08,        //     Report Size (8)
0x95, 0x01,        //     Report Count (1)
0x81, 0x02,        //     Input (Data,Var,Abs,No Wrap,Linear,Preferred State,No Null Position)
0x05, 0x01,        //     Usage Page (Generic Desktop Ctrls)
0x09, 0x30,        //     Usage (X)
0x75, 0x10,        //     Report Size (16)
0x55, 0x0E,        //     Unit Exponent (-2)
0x65, 0x11,        //     Unit (System: SI Linear, Length: Centimeter)
0x35, 0x00,        //     Physical Minimum (0)
0x46, 0x5A, 0x04,  //     Physical Maximum (1114)
0x27, 0x39, 0x05, 0x00, 0x00,  //     Logical Maximum (1336)
0x81, 0x02,        //     Input (Data,Var,Abs,No Wrap,Linear,Preferred State,No Null Position)
0x09, 0x31,        //     Usage (Y)
0x46, 0xDA, 0x02,  //     Physical Maximum (730)
0x27, 0x6C, 0x03, 0x00, 0x00,  //     Logical Maximum (875)
0x81, 0x02,        //     Input (Data,Var,Abs,No Wrap,Linear,Preferred State,No Null Position)
0xC0,              //   End Collection
0x05, 0x0D,        //   Usage Page (Digitizer)
0x09, 0x54,        //   Usage (0x54)
0x15, 0x00,        //   Logical Minimum (0)
0x25, 0x05,        //   Logical Maximum (5)
0x75, 0x08,        //   Report Size (8)
0x95, 0x01,        //   Report Count (1)
0x81, 0x02,        //   Input (Data,Var,Abs,No Wrap,Linear,Preferred State,No Null Position)
0x05, 0x09,        //   Usage Page (Button)
0x09, 0x01,        //   Usage (0x01)
0x09, 0x02,        //   Usage (0x02)
0x09, 0x03,        //   Usage (0x03)
0x15, 0x00,        //   Logical Minimum (0)
0x25, 0x01,        //   Logical Maximum (1)
0x75, 0x01,        //   Report Size (1)
0x95, 0x03,        //   Report Count (3)
0x81, 0x02,        //   Input (Data,Var,Abs,No Wrap,Linear,Preferred State,No Null Position)
0x95, 0x05,        //   Report Count (5)
0x81, 0x03,        //   Input (Const,Var,Abs,No Wrap,Linear,Preferred State,No Null Position)
0x05, 0x0D,        //   Usage Page (Digitizer)
0x09, 0x56,        //   Usage (0x56)
0x55, 0x0C,        //   Unit Exponent (-4)
0x66, 0x01, 0x10,  //   Unit (System: SI Linear, Time: Seconds)
0x35, 0x00,        //   Physical Minimum (0)
0x47, 0xFF, 0xFF, 0x00, 0x00,  //   Physical Maximum (65534)
0x15, 0x00,        //   Logical Minimum (0)
0x27, 0xFF, 0xFF, 0x00, 0x00,  //   Logical Maximum (65534)
0x75, 0x10,        //   Report Size (16)
0x95, 0x01,        //   Report Count (1)
0x81, 0x02,        //   Input (Data,Var,Abs,No Wrap,Linear,Preferred State,No Null Position)
0x05, 0x0D,        //   Usage Page (Digitizer)
0x09, 0x55,        //   Usage (0x55)
0x15, 0x00,        //   Logical Minimum (0)
0x25, 0x05,        //   Logical Maximum (5)
0x75, 0x08,        //   Report Size (8)
0x95, 0x01,        //   Report Count (1)
0x85, 0x03,        //   Report ID (3)
0xB1, 0x02,        //   Feature (Data,Var,Abs,No Wrap,Linear,Preferred State,No Null Position,Non-volatile)
0x05, 0x0D,        //   Usage Page (Digitizer)
0x09, 0x59,        //   Usage (0x59)
0x15, 0x00,        //   Logical Minimum (0)
0x25, 0x0F,        //   Logical Maximum (15)
0x75, 0x08,        //   Report Size (8)
0x95, 0x01,        //   Report Count (1)
0x85, 0x04,        //   Report ID (4)
0xB1, 0x02,        //   Feature (Data,Var,Abs,No Wrap,Linear,Preferred State,No Null Position,Non-volatile)
0x06, 0x00, 0xFF,  //   Usage Page (Vendor Defined 0xFF00)
0x85, 0x05,        //   Report ID (5)
0x75, 0x08,        //   Report Size (8)
0x15, 0x00,        //   Logical Minimum (0)
0x09, 0xC6,        //   Usage (0xC6)
0x25, 0x08,        //   Logical Maximum (8)
0x95, 0x01,        //   Report Count (1)
0xB1, 0x02,        //   Feature (Data,Var,Abs,No Wrap,Linear,Preferred State,No Null Position,Non-volatile)
0x09, 0xC7,        //   Usage (0xC7)
0x26, 0xFF, 0x00,  //   Logical Maximum (255)
0x95, 0x20,        //   Report Count (32)
0xB1, 0x02,        //   Feature (Data,Var,Abs,No Wrap,Linear,Preferred State,No Null Position,Non-volatile)
0xC0,              // End Collection
0x05, 0x0D,        // Usage Page (Digitizer)
0x09, 0x0E,        // Usage (0x0E)
0xA1, 0x01,        // Collection (Application)
0x05, 0x0D,        //   Usage Page (Digitizer)
0x09, 0x22,        //   Usage (Finger)
0xA1, 0x02,        //   Collection (Logical)
0x09, 0x52,        //     Usage (0x52)
0x15, 0x00,        //     Logical Minimum (0)
0x25, 0x0A,        //     Logical Maximum (10)
0x75, 0x08,        //     Report Size (8)
0x95, 0x01,        //     Report Count (1)
0x85, 0x06,        //     Report ID (6)
0xB1, 0x02,        //     Feature (Data,Var,Abs,No Wrap,Linear,Preferred State,No Null Position,Non-volatile)
0xC0,              //   End Collection
0x05, 0x0D,        //   Usage Page (Digitizer)
0x09, 0x22,        //   Usage (Finger)
0xA1, 0x00,        //   Collection (Physical)
0x09, 0x57,        //     Usage (0x57)
0x09, 0x58,        //     Usage (0x58)
0x15, 0x00,        //     Logical Minimum (0)
0x25, 0x01,        //     Logical Maximum (1)
0x75, 0x01,        //     Report Size (1)
0x95, 0x02,        //     Report Count (2)
0x85, 0x07,        //     Report ID (7)
0xB1, 0x02,        //     Feature (Data,Var,Abs,No Wrap,Linear,Preferred State,No Null Position,Non-volatile)
0x95, 0x06,        //     Report Count (6)
0xB1, 0x03,        //     Feature (Const,Var,Abs,No Wrap,Linear,Preferred State,No Null Position,Non-volatile)
0xC0,              //   End Collection
0x05, 0x0D,        //   Usage Page (Digitizer)
0x09, 0x60,        //   Usage (0x60)
0x15, 0x00,        //   Logical Minimum (0)
0x25, 0x01,        //   Logical Maximum (1)
0x75, 0x01,        //   Report Size (1)
0x95, 0x01,        //   Report Count (1)
0x85, 0x08,        //   Report ID (8)
0xB1, 0x02,        //   Feature (Data,Var,Abs,No Wrap,Linear,Preferred State,No Null Position,Non-volatile)
0x95, 0x07,        //   Report Count (7)
0xB1, 0x03,        //   Feature (Const,Var,Abs,No Wrap,Linear,Preferred State,No Null Position,Non-volatile)
0xC0,              // End Collection
0x06, 0x00, 0xFF,  // Usage Page (Vendor Defined 0xFF00)
0x09, 0x01,        // Usage (0x01)
0xA1, 0x01,        // Collection (Application)
0x85, 0x42,        //   Report ID (66)
0x09, 0x06,        //   Usage (0x06)
0x15, 0x00,        //   Logical Minimum (0)
0x26, 0xFF, 0x00,  //   Logical Maximum (255)
0x75, 0x08,        //   Report Size (8)
0x95, 0x03,        //   Report Count (3)
0xB1, 0x02,        //   Feature (Data,Var,Abs,No Wrap,Linear,Preferred State,No Null Position,Non-volatile)
0x06, 0x00, 0xFF,  //   Usage Page (Vendor Defined 0xFF00)
0x09, 0x05,        //   Usage (0x05)
0x15, 0x00,        //   Logical Minimum (0)
0x26, 0xFF, 0x00,  //   Logical Maximum (255)
0x75, 0x08,        //   Report Size (8)
0x96, 0x00, 0x01,  //   Report Count (256)
0x85, 0x41,        //   Report ID (65)
0xB1, 0x02,        //   Feature (Data,Var,Abs,No Wrap,Linear,Preferred State,No Null Position,Non-volatile)
0x85, 0x43,        //   Report ID (67)
0x09, 0x06,        //   Usage (0x06)
0x15, 0x00,        //   Logical Minimum (0)
0x26, 0xFF, 0x00,  //   Logical Maximum (255)
0x75, 0x08,        //   Report Size (8)
0x95, 0x03,        //   Report Count (3)
0xB1, 0x02,        //   Feature (Data,Var,Abs,No Wrap,Linear,Preferred State,No Null Position,Non-volatile)
0xC0,              // End Collection

// 687 bytes

```

But this value looks static; should read up on what exactly I'm looking at.

And, can this be read from FT260 now?

# 10/17/24 

Did some homework and of course, HID report descriptor is not a report so it is supposed to be static. 
Whatever I was reading earlier was indeed a HID report, and the 687 bytes long descriptor is schematics on how to interpret that report.

Time to go get the reports back again...

1 finger 
```
03 01 69 02 9d 00
00000011 00000001 01101001 00000010 10011101 00000000 

00 00 00 00 00 00
00000000 00000000 00000000 00000000 00000000 00000000 

00 00 00 00 00 00
00000000 00000000 00000000 00000000 00000000 00000000 

00 00 00 00 00 00
00000000 00000000 00000000 00000000 00000000 00000000 

00 00 00 00 00 00
00000000 00000000 00000000 00000000 00000000 00000000 

01 00 b9 7a
00000001 00000000 10111001 01111010
```

3 finger 
```
03 00 60 02 fe 00 
00000011 00000000 01100000 00000010 11111110 00000000 

03 01 6b 03 58 01
00000011 00000001 01101011 00000011 01011000 00000001

03 02 5c 01 b0 01
00000011 00000010 01011100 00000001 10110000 00000001 

00 00 00 00 00 00
00000000 00000000 00000000 00000000 00000000 00000000

00 00 00 00 00 00
00000000 00000000 00000000 00000000 00000000 00000000 

03 00 b5 91
00000011 00000000 10110101 10010001
```

5 finger 
```
03 00 92 03 a7 00
00000011 00000000 10010010 00000011 10100111 00000000

03 01 8b 02 46 00
00000011 00000001 10001011 00000010 01000110 00000000

03 02 9e 01 00 01
00000011 00000010 10011110 00000001 00000000 00000001

03 03 41 04 99 01
00000011 00000011 01000001 00000100 10011001 00000001

03 04 2e 01 92 02
00000011 00000100 00101110 00000001 10010010 00000010

05 00 f3 7f
00000101 00000000 11110011 01111111
```
Total 272 bits = 34 bytes 

Now to break this down using the descriptor... 

# 10/19/2024

Found some more interesting information. Microsoft has this [Required I2C HID Descriptor](https://learn.microsoft.com/en-us/windows-hardware/design/component-guidelines/touchpad-required-hid-descriptors) table available, and I found the exact report in the touchpad output. 

In register 32:

| | wHIDDescLength | bcdVersion| wReportDescLength | wReportDescRegister | wInputRegister | wMaxInputLength | wOutputRegister | wMaxOutputLength | wCommandRegister| wDataRegister | wVendorID| wDeviceID | wVersionID |
|--- | --- | --- | --- | --- | --- | --- | --- | --- | --- | --- | --- | ----  | ----  |
| index | 00 01 | 02 03 | 04 05 | 06 07 | 08 09 | 10 11 | 12 13 | 14 15 | 16 17 | 18 19 | 20 21 | 22 23 | 24 25 |
| value | 1e 00 | 00 01 | af 02 | 21 00 | 24 00 | 25 00 | 25 00 | 00 00 | 22 00 | 23 00 | 3a 09 | 74 02 | 04 07 |

| Member | Size in Bytes | Description | value in hex | value in dec or decoded |
| ---- | ---- | ---- | ---- | ---- |
| wHIDDescLength | 2 | The length of the complete HID descriptor (in Bytes) |  `1e 00` = `0x001e` | 30 |
| bcdVersion | 2 | The version number, in binary coded decimal format | `00 01` = `0x0100` | 4 |
| wReportDescLength | 2 | The length of the Report descriptor (in Bytes) | `af 02` = `0x02af` | 687 |
| wReportDescRegister | 2 | The register index containing the report descriptor | `21 00` = `0x21` | 33 |
| wInputRegister | 2 | The register number to read the input report | `24 00` = `0x24` | 36 | 
| wMaxInputLength | 2 | The length of the largest input report to be read from the input register | `25 00` = `0x25` | 37 |
| wOutputRegister | 2 | The register number to send the output | `25 00` = `0x25` | 37 |
| wMaxOutputLength | 2 | The length of the largest output report to be sent | `00 00` = `0x00` | 0 |
| wCommandRegister | 2 | The register number to send command requests | `22 00` = `0x22` | 34 |
| wDataRegister | 2 | The register number to exchange data with command requests | `23 00` = `0x23` | 35 | 
| wVendorID | 2 | USB-IF assigned Vendor ID | `3a 09` = `0x093a` | 2362 |
| wDeviceID | 2 | Device ID | `74 02` = `0x0274` | 628 | 
| wVersionID | 2 | Firmware version number | `04 07` = `0x0704` | 1796 | 

Pure luck I found the descriptor, but it was indeed in `0x21` and the total length of the descriptor is in fact 687 bytes.

It says the input report should be read from register `0x24`, and the length of the largest input report to be read from the input register is 0x25 = 37

And from USB-IF Vendor ID look ups, PixArt's ID is indeed `093A`. Device ID did not show up under their product list though. 

Data from register `0x24`:
```
00 01 02 03 04 05 06 07 08 09 10 11 12 13 14 15 16 17 18 19 20 21 22 23 24 25 26 27 28 29 30 31 32 33 34 35 36
00 00 01 01 00 d9 00 5b 03 01 02 3f 02 37 03 00 00 00 00 00 00 00 00 00 00 00 00 00 00 00 00 00 00 02 00 3e 64
00 00 01 03 00 08 02 56 01 03 01 04 01 e7 01 00 00 00 00 00 00 00 00 00 00 00 00 00 00 00 00 00 00 02 00 13 64 
00 00 01 03 00 08 02 56 01 03 01 04 01 e7 01 00 00 00 00 00 00 00 00 00 00 00 00 00 00 00 00 00 00 02 00 13 64
```
Somewhat static? 

# 10/22/2024 

Reading through the descriptor, I think I have better idea of what is going on in the report. 

This is the descriptor for a single finger. 

```
b'\x05\x0D'       #   Usage Page (Digitizer)
b'\x09\x22'       #   Usage (Finger)
b'\xA1\x02'       #   Collection (Logical)
b'\x09\x47'       #     Usage (\x47) -> **Touch Valid**
b'\x09\x42'       #     Usage (Tip Switch)
b'\x15\x00'       #     Logical Minimum (0)
b'\x25\x01'       #     Logical Maximum (1)
b'\x75\x01'       #     Report Size (1)
b'\x95\x02'       #     Report Count (2)
b'\x81\x02'       #     Input (Data,Var,Abs,No Wrap,Linear,Preferred State,No Null Position)
b'\x95\x06'       #     Report Count (6)
b'\x81\x03'       #     Input (Const,Var,Abs,No Wrap,Linear,Preferred State,No Null Position)
b'\x09\x51'       #     Usage (\x51) -> **Contact Identifier**
b'\x25\x0F'       #     Logical Maximum (15)
b'\x75\x08'       #     Report Size (8)
b'\x95\x01'       #     Report Count (1)
b'\x81\x02'       #     Input (Data,Var,Abs,No Wrap,Linear,Preferred State,No Null Position)
b'\x05\x01'       #     Usage Page (Generic Desktop Ctrls)
b'\x09\x30'       #     Usage (X)
b'\x75\x10'       #     Report Size (16)
b'\x55\x0E'       #     Unit Exponent (-2)
b'\x65\x11'       #     Unit (System: SI Linear'Length: Centimeter)
b'\x35\x00'       #     Physical Minimum (0)
b'\x46\x5A\x04' #     Physical Maximum (1114)
b'\x27\x39\x05\x00\x00' #     Logical Maximum (1336)
b'\x81\x02'       #     Input (Data,Var,Abs,No Wrap,Linear,Preferred State,No Null Position)
b'\x09\x31'       #     Usage (Y)
b'\x46\xDA\x02' #     Physical Maximum (730)
b'\x27\x6C\x03\x00\x00' #     Logical Maximum (875)
b'\x81\x02'       #     Input (Data,Var,Abs,No Wrap,Linear,Preferred State,No Null Position)
```

Usage (0x47) is followed by Usage (0x42 - Tip Switch). According to [Microsoft documentation for Digitizer Report Descriptors](https://learn.microsoft.com/en-us/windows-hardware/design/component-guidelines/supporting-usages-in-digitizer-report-descriptors), 0x47 is for Confidence (or Touch Valid in [HID Usage Tables 1.5](https://usb.org/document-library/hid-usage-tables-15) and 0x42 is for Tip (Tip Switch?).

> Touch Valid: Indicates the device’s confidence that the touch contact was an intended, valid
contact. The device should report 0 if the contact is not a valid touch. The device
should report 1 if the contact is intended and valid (e.g. a pointing touch)

> Tip Switch: A switch located at the tip of a stylus, indicating contact of the stylus with a surface.
A pen-based system or system extension would use this switch to enable the input
of handwriting or gesture data. The system typically maps Tip Switch to a primary
button in a non-pen context

So one bit for Confidence, another bit for Tip each with Logical Minimum 0 to Logical Maximum 1. And some padding for 6 bits? 

And for Usage 0x51, [HID Usage Tables 1.5](https://usb.org/document-library/hid-usage-tables-15) indicates that byte 0x51 corresponds to Contact Identifier. So That is indeed the finger index. 

> Contact Identifier: An identifier associated with a contact. The id persists for the duration of that
contact’s detection, but may be reused for another contact once the original is no
longer detected. Detection is assumed to extend from contact down to contact
up notifications (or for devices that support hover detection, contact in-range to
out-of-range).

So for each finger, I have the following:

| Finger 0 Confidence + Tip Switch | Finger 0 index | Finger 0 X Lower Byte | Finger 0 X Higher Byte | Finger 0 Y  Lower Byte | Finger 0 Y Higher Byte | 
|---|---|---|---|---|---|
|03 | 00 | f3 | 04 | 37 | 00 |

And after 5 fingers, I have this section

```
b'\x05\x0D'       #   Usage Page (Digitizer)
b'\x09\x54'       #   Usage (\x54) -> **Contact Count**
b'\x15\x00'       #   Logical Minimum (0)
b'\x25\x05'       #   Logical Maximum (5)
b'\x75\x08'       #   Report Size (8)
b'\x95\x01'       #   Report Count (1)
b'\x81\x02'       #   Input (Data,Var,Abs,No Wrap,Linear,Preferred State,No Null Position)
b'\x05\x09'       #   Usage Page (Button)
b'\x09\x01'       #   Usage (\x01)
b'\x09\x02'       #   Usage (\x02)
b'\x09\x03'       #   Usage (\x03)
b'\x15\x00'       #   Logical Minimum (0)
b'\x25\x01'       #   Logical Maximum (1)
b'\x75\x01'       #   Report Size (1)
b'\x95\x03'       #   Report Count (3)
b'\x81\x02'       #   Input (Data,Var,Abs,No Wrap,Linear,Preferred State,No Null Position)
b'\x95\x05'       #   Report Count (5)
b'\x81\x03'       #   Input (Const,Var,Abs,No Wrap,Linear,Preferred State,No Null Position)
b'\x05\x0D'       #   Usage Page (Digitizer)
b'\x09\x56'       #   Usage (\x56) -> **Scan Time**
b'\x55\x0C'       #   Unit Exponent (-4)
b'\x66\x01\x10' #   Unit (System: SI Linear'Time: Seconds)
b'\x35\x00'       #   Physical Minimum (0)
b'\x47\xFF\xFF\x00\x00' #   Physical Maximum (65534)
b'\x15\x00'       #   Logical Minimum (0)
b'\x27\xFF\xFF\x00\x00' #   Logical Maximum (65534)
b'\x75\x10'       #   Report Size (16)
b'\x95\x01'       #   Report Count (1)
b'\x81\x02'       #   Input (Data,Var,Abs,No Wrap,Linear,Preferred State,No Null Position)
```

Usage 0x54 means Contact Count, so that matches my earlier analysis that this byte indicates number of total detected fingers. 

> Contact Count: The current number of contacts the digitizer detects and is reporting.

The second byte is for Button, which consists of 3 bits for each button. I don't think this touchpad module can do button presses unless it is mounted to some external frame like it is on an actual framework laptop. So it will always be 0 for me. Or maybe the touchpad supports actual buttons like in Thinkpad touch pads. 

Finally the remaining data has usage 0x56, which is Scan Time. This ranges from 0 to 65534, so I guess it uses the remaining two bytes. So it was not report ID, but instead the serial time data of the particular touch. 

> Scan Time: For each frame reported, the digitizer shall report a timestamp in relative time. The
units are in 100 microseconds by default. The first scan time received is treated as
a base time for subsequent reported times. This value represents the time difference
from the first frame that was reported after a device starts reporting data subsequent
to a period of inactivity. The time differences between reported scan times should
reflect the scanning frequency of the digitizer. The scan time value should be the
same for all contacts within a frame.

| Number of fingers | Number of Buttons pressed  | Scan time lower byte | Scan time higher byte |
| --- | --- | --- | --- |
|05 | 00 | e2 | d5 |

That's everything!

| | Finger 0 Confidence + Tip Switch | Finger 0 index | Finger 0 X Lower Byte | Finger 0 X Higher Byte | Finger 0 Y  Lower Byte | Finger 0 Y Higher Byte | Finger 1  Confidence + Tip Switch | Finger 1 index | Finger 1 X Lower Byte | Finger 1 X Higher Byte | Finger 1 Y  Lower Byte | Finger 1 Y Higher Byte | Finger 2 Confidence + Tip Switch | Finger 2 index | Finger 2 X Lower Byte | Finger 2 X Higher Byte | Finger 2 Y  Lower Byte | Finger 2 Y Higher Byte | Finger 3 Confidence + Tip Switch | Finger 3 index | Finger 3 X Lower Byte | Finger 3 X Higher Byte | Finger 3 Y  Lower Byte | Finger 3 Y Higher Byte | Finger 4 Confidence + Tip Switch | Finger 4 index | Finger 4 X Lower Byte | Finger 4 X Higher Byte | Finger 4 Y  Lower Byte | Finger 4 Y Higher Byte | Number of fingers (Contact Count) | Number of Buttons pressed  | Scan time lower byte | Scan time higher byte |
|---|---|---|---|---|---|---|---|---|---|---|---|---|---|---|---|---|---|---|---|---|---|---|---|---|---|---|---|---|---|---| --- | --- | --- | --- |
|index | 00| 01 |02|03|04|05|06|07|08|09|10|11|12|13|14|15|16|17|18|19|20|21|22|23|24|25|26|27|28|29|30|31|32|33|
| byte |03 | 00 | f3 | 04 | 37 | 00 |03 | 01 | f3 | 04 | 37 | 00 |03 | 02 | f3 | 04 | 37 | 00 |03 | 03 | f3 | 04 | 37 | 00 |03 | 04 | f3 | 04 | 37 | 00 | 05 | 00 | e2 | d5 |

What's odd is I could not read the input report from register 0x24. It was available by just doing a read on I2C device at 0x2C directly. 

Now that I know what the HID report means, next step is to check if operating system can readily pick this up when I forward it.

While the descriptor is 687 bytes long, it looks like the only relevant part of the descriptor is the following: 

```
0x05, 0x0D,        // Usage Page (Digitizer)
0x09, 0x05,        // Usage (Touch Pad)
0xA1, 0x01,        // Collection (Application)
0x85, 0x01,        //   Report ID (1)
0x05, 0x0D,        //   Usage Page (Digitizer)
0x09, 0x22,        //   Usage (Finger)
0xA1, 0x02,        //   Collection (Logical)
0x09, 0x47,        //     Usage (Confidence / Touch Valid)
0x09, 0x42,        //     Usage (Tip Switch)
0x15, 0x00,        //     Logical Minimum (0)
0x25, 0x01,        //     Logical Maximum (1)
0x75, 0x01,        //     Report Size (1)
0x95, 0x02,        //     Report Count (2)
0x81, 0x02,        //     Input (Data,Var,Abs,No Wrap,Linear,Preferred State,No Null Position)
0x95, 0x06,        //     Report Count (6)
0x81, 0x03,        //     Input (Const,Var,Abs,No Wrap,Linear,Preferred State,No Null Position)
0x09, 0x51,        //     Usage (Contact Identifier - Finger index)
0x25, 0x0F,        //     Logical Maximum (15)
0x75, 0x08,        //     Report Size (8)
0x95, 0x01,        //     Report Count (1)
0x81, 0x02,        //     Input (Data,Var,Abs,No Wrap,Linear,Preferred State,No Null Position)
0x05, 0x01,        //     Usage Page (Generic Desktop Ctrls)
0x09, 0x30,        //     Usage (X)
0x75, 0x10,        //     Report Size (16)
0x55, 0x0E,        //     Unit Exponent (-2)
0x65, 0x11,        //     Unit (System: SI Linear, Length: Centimeter)
0x35, 0x00,        //     Physical Minimum (0)
0x46, 0x5A, 0x04,  //     Physical Maximum (1114)
0x27, 0x39, 0x05, 0x00, 0x00,  //     Logical Maximum (1336)
0x81, 0x02,        //     Input (Data,Var,Abs,No Wrap,Linear,Preferred State,No Null Position)
0x09, 0x31,        //     Usage (Y)
0x46, 0xDA, 0x02,  //     Physical Maximum (730)
0x27, 0x6C, 0x03, 0x00, 0x00,  //     Logical Maximum (875)
0x81, 0x02,        //     Input (Data,Var,Abs,No Wrap,Linear,Preferred State,No Null Position)
0xC0,              //   End Collection
0x05, 0x0D,        //   Usage Page (Digitizer)
0x09, 0x22,        //   Usage (Finger)
0xA1, 0x02,        //   Collection (Logical)
0x09, 0x47,        //     Usage (Confidence / Touch Valid)
0x09, 0x42,        //     Usage (Tip Switch)
0x15, 0x00,        //     Logical Minimum (0)
0x25, 0x01,        //     Logical Maximum (1)
0x75, 0x01,        //     Report Size (1)
0x95, 0x02,        //     Report Count (2)
0x81, 0x02,        //     Input (Data,Var,Abs,No Wrap,Linear,Preferred State,No Null Position)
0x95, 0x06,        //     Report Count (6)
0x81, 0x03,        //     Input (Const,Var,Abs,No Wrap,Linear,Preferred State,No Null Position)
0x09, 0x51,        //     Usage (Contact Identifier - Finger index)
0x25, 0x0F,        //     Logical Maximum (15)
0x75, 0x08,        //     Report Size (8)
0x95, 0x01,        //     Report Count (1)
0x81, 0x02,        //     Input (Data,Var,Abs,No Wrap,Linear,Preferred State,No Null Position)
0x05, 0x01,        //     Usage Page (Generic Desktop Ctrls)
0x09, 0x30,        //     Usage (X)
0x75, 0x10,        //     Report Size (16)
0x55, 0x0E,        //     Unit Exponent (-2)
0x65, 0x11,        //     Unit (System: SI Linear, Length: Centimeter)
0x35, 0x00,        //     Physical Minimum (0)
0x46, 0x5A, 0x04,  //     Physical Maximum (1114)
0x27, 0x39, 0x05, 0x00, 0x00,  //     Logical Maximum (1336)
0x81, 0x02,        //     Input (Data,Var,Abs,No Wrap,Linear,Preferred State,No Null Position)
0x09, 0x31,        //     Usage (Y)
0x46, 0xDA, 0x02,  //     Physical Maximum (730)
0x27, 0x6C, 0x03, 0x00, 0x00,  //     Logical Maximum (875)
0x81, 0x02,        //     Input (Data,Var,Abs,No Wrap,Linear,Preferred State,No Null Position)
0xC0,              //   End Collection
0x05, 0x0D,        //   Usage Page (Digitizer)
0x09, 0x22,        //   Usage (Finger)
0xA1, 0x02,        //   Collection (Logical)
0x09, 0x47,        //     Usage (Confidence / Touch Valid)
0x09, 0x42,        //     Usage (Tip Switch)
0x15, 0x00,        //     Logical Minimum (0)
0x25, 0x01,        //     Logical Maximum (1)
0x75, 0x01,        //     Report Size (1)
0x95, 0x02,        //     Report Count (2)
0x81, 0x02,        //     Input (Data,Var,Abs,No Wrap,Linear,Preferred State,No Null Position)
0x95, 0x06,        //     Report Count (6)
0x81, 0x03,        //     Input (Const,Var,Abs,No Wrap,Linear,Preferred State,No Null Position)
0x09, 0x51,        //     Usage (Contact Identifier - Finger index)
0x25, 0x0F,        //     Logical Maximum (15)
0x75, 0x08,        //     Report Size (8)
0x95, 0x01,        //     Report Count (1)
0x81, 0x02,        //     Input (Data,Var,Abs,No Wrap,Linear,Preferred State,No Null Position)
0x05, 0x01,        //     Usage Page (Generic Desktop Ctrls)
0x09, 0x30,        //     Usage (X)
0x75, 0x10,        //     Report Size (16)
0x55, 0x0E,        //     Unit Exponent (-2)
0x65, 0x11,        //     Unit (System: SI Linear, Length: Centimeter)
0x35, 0x00,        //     Physical Minimum (0)
0x46, 0x5A, 0x04,  //     Physical Maximum (1114)
0x27, 0x39, 0x05, 0x00, 0x00,  //     Logical Maximum (1336)
0x81, 0x02,        //     Input (Data,Var,Abs,No Wrap,Linear,Preferred State,No Null Position)
0x09, 0x31,        //     Usage (Y)
0x46, 0xDA, 0x02,  //     Physical Maximum (730)
0x27, 0x6C, 0x03, 0x00, 0x00,  //     Logical Maximum (875)
0x81, 0x02,        //     Input (Data,Var,Abs,No Wrap,Linear,Preferred State,No Null Position)
0xC0,              //   End Collection
0x05, 0x0D,        //   Usage Page (Digitizer)
0x09, 0x22,        //   Usage (Finger)
0xA1, 0x02,        //   Collection (Logical)
0x09, 0x47,        //     Usage (Confidence / Touch Valid)
0x09, 0x42,        //     Usage (Tip Switch)
0x15, 0x00,        //     Logical Minimum (0)
0x25, 0x01,        //     Logical Maximum (1)
0x75, 0x01,        //     Report Size (1)
0x95, 0x02,        //     Report Count (2)
0x81, 0x02,        //     Input (Data,Var,Abs,No Wrap,Linear,Preferred State,No Null Position)
0x95, 0x06,        //     Report Count (6)
0x81, 0x03,        //     Input (Const,Var,Abs,No Wrap,Linear,Preferred State,No Null Position)
0x09, 0x51,        //     Usage (Contact Identifier - Finger index)
0x25, 0x0F,        //     Logical Maximum (15)
0x75, 0x08,        //     Report Size (8)
0x95, 0x01,        //     Report Count (1)
0x81, 0x02,        //     Input (Data,Var,Abs,No Wrap,Linear,Preferred State,No Null Position)
0x05, 0x01,        //     Usage Page (Generic Desktop Ctrls)
0x09, 0x30,        //     Usage (X)
0x75, 0x10,        //     Report Size (16)
0x55, 0x0E,        //     Unit Exponent (-2)
0x65, 0x11,        //     Unit (System: SI Linear, Length: Centimeter)
0x35, 0x00,        //     Physical Minimum (0)
0x46, 0x5A, 0x04,  //     Physical Maximum (1114)
0x27, 0x39, 0x05, 0x00, 0x00,  //     Logical Maximum (1336)
0x81, 0x02,        //     Input (Data,Var,Abs,No Wrap,Linear,Preferred State,No Null Position)
0x09, 0x31,        //     Usage (Y)
0x46, 0xDA, 0x02,  //     Physical Maximum (730)
0x27, 0x6C, 0x03, 0x00, 0x00,  //     Logical Maximum (875)
0x81, 0x02,        //     Input (Data,Var,Abs,No Wrap,Linear,Preferred State,No Null Position)
0xC0,              //   End Collection
0x05, 0x0D,        //   Usage Page (Digitizer)
0x09, 0x22,        //   Usage (Finger)
0xA1, 0x02,        //   Collection (Logical)
0x09, 0x47,        //     Usage (Confidence / Touch Valid)
0x09, 0x42,        //     Usage (Tip Switch)
0x15, 0x00,        //     Logical Minimum (0)
0x25, 0x01,        //     Logical Maximum (1)
0x75, 0x01,        //     Report Size (1)
0x95, 0x02,        //     Report Count (2)
0x81, 0x02,        //     Input (Data,Var,Abs,No Wrap,Linear,Preferred State,No Null Position)
0x95, 0x06,        //     Report Count (6)
0x81, 0x03,        //     Input (Const,Var,Abs,No Wrap,Linear,Preferred State,No Null Position)
0x09, 0x51,        //     Usage (Contact Identifier - Finger index)
0x25, 0x0F,        //     Logical Maximum (15)
0x75, 0x08,        //     Report Size (8)
0x95, 0x01,        //     Report Count (1)
0x81, 0x02,        //     Input (Data,Var,Abs,No Wrap,Linear,Preferred State,No Null Position)
0x05, 0x01,        //     Usage Page (Generic Desktop Ctrls)
0x09, 0x30,        //     Usage (X)
0x75, 0x10,        //     Report Size (16)
0x55, 0x0E,        //     Unit Exponent (-2)
0x65, 0x11,        //     Unit (System: SI Linear, Length: Centimeter)
0x35, 0x00,        //     Physical Minimum (0)
0x46, 0x5A, 0x04,  //     Physical Maximum (1114)
0x27, 0x39, 0x05, 0x00, 0x00,  //     Logical Maximum (1336)
0x81, 0x02,        //     Input (Data,Var,Abs,No Wrap,Linear,Preferred State,No Null Position)
0x09, 0x31,        //     Usage (Y)
0x46, 0xDA, 0x02,  //     Physical Maximum (730)
0x27, 0x6C, 0x03, 0x00, 0x00,  //     Logical Maximum (875)
0x81, 0x02,        //     Input (Data,Var,Abs,No Wrap,Linear,Preferred State,No Null Position)
0xC0,              //   End Collection
0x05, 0x0D,        //   Usage Page (Digitizer)
0x09, 0x54,        //   Usage (Contact Count)
0x15, 0x00,        //   Logical Minimum (0)
0x25, 0x05,        //   Logical Maximum (5)
0x75, 0x08,        //   Report Size (8)
0x95, 0x01,        //   Report Count (1)
0x81, 0x02,        //   Input (Data,Var,Abs,No Wrap,Linear,Preferred State,No Null Position)
0x05, 0x09,        //   Usage Page (Button)
0x09, 0x01,        //   Usage (0x01)
0x09, 0x02,        //   Usage (0x02)
0x09, 0x03,        //   Usage (0x03)
0x15, 0x00,        //   Logical Minimum (0)
0x25, 0x01,        //   Logical Maximum (1)
0x75, 0x01,        //   Report Size (1)
0x95, 0x03,        //   Report Count (3)
0x81, 0x02,        //   Input (Data,Var,Abs,No Wrap,Linear,Preferred State,No Null Position)
0x95, 0x05,        //   Report Count (5)
0x81, 0x03,        //   Input (Const,Var,Abs,No Wrap,Linear,Preferred State,No Null Position)
0x05, 0x0D,        //   Usage Page (Digitizer)
0x09, 0x56,        //   Usage (Scan Time)
0x55, 0x0C,        //   Unit Exponent (-4)
0x66, 0x01, 0x10,  //   Unit (System: SI Linear, Time: Seconds)
0x35, 0x00,        //   Physical Minimum (0)
0x47, 0xFF, 0xFF, 0x00, 0x00,  //   Physical Maximum (65534)
0x15, 0x00,        //   Logical Minimum (0)
0x27, 0xFF, 0xFF, 0x00, 0x00,  //   Logical Maximum (65534)
0x75, 0x10,        //   Report Size (16)
0x95, 0x01,        //   Report Count (1)
0x81, 0x02,        //   Input (Data,Var,Abs,No Wrap,Linear,Preferred State,No Null Position)
```

There are more information in the descriptor, such as 0x55: Contact Count Maximum, 0x59: Pad Type, Vendor defined 0xFF with 0xC6, 0xC7, 0x01, 0x06,   and 0x05 under it, 0x0E: Device Configuration, 0x57: Surface Switch, 0x58: Button Switch, and 0x60: Latency Mode but not all of them are in the report.

# 12/22/2024

After spending a lot of time going over MicroPython's USB HID library and its example codes, I now have a "somewhat working" code that can read and publish HID report over USB. 

But nothing is happening. 

Sometime this fall I finally gave in and purchased Framework 13, so I now had a solid answer to compare my data from the Pico. I connected my device to the laptop for debugging. 

Using lsusb, I saw my device did indeed show up correctly: 

```
$ lsusb
Bus 005 Device 012: ID 2e8a:0005 MicroPython Board in FS mode
```

Using `usbhid-dump -d2e8a:0005 -es`, I saw "something" was coming out of my device but it looked wrong. 

Turns out, my descriptor was incorrect according to `usbhid-dump -d2e8a:0005 -ed`. 

I made a mistake while converting descriptor format from the [Online Descriptor Analysis tool](http://eleccelerator.com/usbdescreqparser/) into Python byte array.. After correcting the data, I confirmed the descriptor from `usbhid-dump` matches the one I defined in my firmware code (trimmed down version that contains only the relevant information). 

```
$ usbhid-dump -d2e8a:0005 -ed
005:012:002:DESCRIPTOR         1734844197.053573
 05 0D 09 05 A1 01 85 01 05 0D 09 22 A1 02 09 47
 09 42 15 00 25 01 75 01 95 02 81 02 95 06 81 03
 09 51 25 0F 75 08 95 01 81 02 05 01 09 30 75 10
 55 0E 65 11 35 00 46 5A 04 27 39 05 00 00 81 02
 09 31 46 DA 02 27 6C 03 00 00 81 02 C0 05 0D 09
 22 A1 02 09 47 09 42 15 00 25 01 75 01 95 02 81
 02 95 06 81 03 09 51 25 0F 75 08 95 01 81 02 05
 01 09 30 75 10 55 0E 65 11 35 00 46 5A 04 27 39
 05 00 00 81 02 09 31 46 DA 02 27 6C 03 00 00 81
 02 C0 05 0D 09 22 A1 02 09 47 09 42 15 00 25 01
 75 01 95 02 81 02 95 06 81 03 09 51 25 0F 75 08
 95 01 81 02 05 01 09 30 75 10 55 0E 65 11 35 00
 46 5A 04 27 39 05 00 00 81 02 09 31 46 DA 02 27
 6C 03 00 00 81 02 C0 05 0D 09 22 A1 02 09 47 09
 42 15 00 25 01 75 01 95 02 81 02 95 06 81 03 09
 51 25 0F 75 08 95 01 81 02 05 01 09 30 75 10 55
 0E 65 11 35 00 46 5A 04 27 39 05 00 00 81 02 09
 31 46 DA 02 27 6C 03 00 00 81 02 C0 05 0D 09 22
 A1 02 09 47 09 42 15 00 25 01 75 01 95 02 81 02
 95 06 81 03 09 51 25 0F 75 08 95 01 81 02 05 01
 09 30 75 10 55 0E 65 11 35 00 46 5A 04 27 39 05
 00 00 81 02 09 31 46 DA 02 27 6C 03 00 00 81 02
 C0 05 0D 09 54 15 00 25 05 75 08 95 01 81 02 05
 09 09 01 09 02 09 03 15 00 25 01 75 01 95 03 81
 02 95 05 81 03 05 0D 09 56 55 0C 66 01 10 35 00
 47 FF FF 00 00 15 00 27 FF FF 00 00 75 10 95 01
 81 02
```

But nothing is happening. 

I then compared my actual report with the expected data from the real touchpad. 

```
$ sudo cat /sys/kernel/debug/hid/0018\:093A\:0274.0002/events
01 03 00 20 05 0c 00 00 00 00 00 00 00 00 00 00 00 00 00 00 00 00 00 00 00 00 00 00 00 00 00 01 00 3c f8
Digitizers.ContactCount = 1
Button.0001 = 0
Button.0002 = 0
Button.0003 = 0
Digitizers.ScanTime = 63548
Digitizers.TipSwitch = 1
Digitizers.TouchValid = 1
Digitizers.ContactIdentifier = 0
GenericDesktop.X = 1312
GenericDesktop.Y = 12
Digitizers.TipSwitch = 0
Digitizers.TouchValid = 0
Digitizers.ContactIdentifier = 0
GenericDesktop.X = 0
GenericDesktop.Y = 0
Digitizers.TipSwitch = 0
Digitizers.TouchValid = 0
Digitizers.ContactIdentifier = 0
GenericDesktop.X = 0
GenericDesktop.Y = 0
Digitizers.TipSwitch = 0
Digitizers.TouchValid = 0
Digitizers.ContactIdentifier = 0
GenericDesktop.X = 0
GenericDesktop.Y = 0
Digitizers.TipSwitch = 0
Digitizers.TouchValid = 0
Digitizers.ContactIdentifier = 0
GenericDesktop.X = 0
GenericDesktop.Y = 0
```

I was glad to see my earlier guesses were correct, but the report did not match what I was sending from the device. I thought I had to send 34 bytes, but the real report was 35 bytes long. After modifying the buffer and inserting 0x01 at the beginning of the report, I'm now sending pretty much the same data as the real touchpad: 

```
$ usbhid-dump -d2e8a:0005 -es
005:012:002:STREAM             1734843878.706360
 01 03 00 24 05 1E 00 00

005:012:002:STREAM             1734843878.714355
 00 00 00 00 00 00 00 00

005:012:002:STREAM             1734843878.722349
 00 00 00 00 00 00 00 00

005:012:002:STREAM             1734843878.730613
 00 00 00 00 00 00 00 01

005:012:002:STREAM             1734843878.738339
 00 BC 00
```

But nothing is happening.

I then checked the HID report descriptor from the real touchpad, and it also matched my earlier 687 bytes long descriptor.

```
$ sudo hexdump -v -e '/1 "%02X "' /sys/bus/hid/devices/0018:093A:0274.0002/report_descriptor 
05 01 09 02 A1 01 85 02 05 01 09 01 A1 00 05 09 19 01 29 02 15 00 25 01 75 01 95 02 81 02 05 0D 09 32 75 01 95 01 81 02 75 05 95 01 81 03 05 01 75 10 95 01 35 00 45 00 16 00 80 26 FF 7F 09 30 81 26 16 00 80 26 FF 7F 09 31 81 26 C0 C0 05 0D 09 05 A1 01 85 01 05 0D 09 22 A1 02 09 47 09 42 15 00 25 01 75 01 95 02 81 02 95 06 81 03 09 51 25 0F 75 08 95 01 81 02 05 01 09 30 75 10 55 0E 65 11 35 00 46 5A 04 27 39 05 00 00 81 02 09 31 46 DA 02 27 6C 03 00 00 81 02 C0 05 0D 09 22 A1 02 09 47 09 42 15 00 25 01 75 01 95 02 81 02 95 06 81 03 09 51 25 0F 75 08 95 01 81 02 05 01 09 30 75 10 55 0E 65 11 35 00 46 5A 04 27 39 05 00 00 81 02 09 31 46 DA 02 27 6C 03 00 00 81 02 C0 05 0D 09 22 A1 02 09 47 09 42 15 00 25 01 75 01 95 02 81 02 95 06 81 03 09 51 25 0F 75 08 95 01 81 02 05 01 09 30 75 10 55 0E 65 11 35 00 46 5A 04 27 39 05 00 00 81 02 09 31 46 DA 02 27 6C 03 00 00 81 02 C0 05 0D 09 22 A1 02 09 47 09 42 15 00 25 01 75 01 95 02 81 02 95 06 81 03 09 51 25 0F 75 08 95 01 81 02 05 01 09 30 75 10 55 0E 65 11 35 00 46 5A 04 27 39 05 00 00 81 02 09 31 46 DA 02 27 6C 03 00 00 81 02 C0 05 0D 09 22 A1 02 09 47 09 42 15 00 25 01 75 01 95 02 81 02 95 06 81 03 09 51 25 0F 75 08 95 01 81 02 05 01 09 30 75 10 55 0E 65 11 35 00 46 5A 04 27 39 05 00 00 81 02 09 31 46 DA 02 27 6C 03 00 00 81 02 C0 05 0D 09 54 15 00 25 05 75 08 95 01 81 02 05 09 09 01 09 02 09 03 15 00 25 01 75 01 95 03 81 02 95 05 81 03 05 0D 09 56 55 0C 66 01 10 35 00 47 FF FF 00 00 15 00 27 FF FF 00 00 75 10 95 01 81 02 05 0D 09 55 15 00 25 05 75 08 95 01 85 03 B1 02 05 0D 09 59 15 00 25 0F 75 08 95 01 85 04 B1 02 06 00 FF 85 05 75 08 15 00 09 C6 25 08 95 01 B1 02 09 C7 26 FF 00 95 20 B1 02 C0 05 0D 09 0E A1 01 05 0D 09 22 A1 02 09 52 15 00 25 0A 75 08 95 01 85 06 B1 02 C0 05 0D 09 22 A1 00 09 57 09 58 15 00 25 01 75 01 95 02 85
```

But the thing is, I was using the trimmed down 481 bytes version... Do I need to use the full descriptor, although the report is not sending any data for the later sections of the report?

# 12/22/2024

My goodness, after changing the descriptor to match the one that's sent from the device, the touchpad just started working. Even the gestures are working. In fact, the "Commit changes..." button will be clicked using the touchpad module.
- Report is 35 bytes long
- Report descriptor has to be the complete thing as is defined

It is a little clunky, probably because the report sent from the micropython firmware is not optimized. 

I guess I did not realize how simple the HID standard is supposed to be. It is supposed to just work, as long as the report descriptor and report is sent to the host device. And it does not matter what the transport medium is, be it I2C or USB. 

Having a reference to compare the descriptor and report from an actual framework laptop was very helpful, but I am fairly confident the same methods I've tried to read the data from this device can readily be applied to any HID over I2C touchpad devices out there. 

Now for the next steps. 

0. Clean up this read me into a proper write up
  - since this readme is a mess, it could use some clean up 
1. Refine the firmware code so that the experience is comparable to the one installed in the actual laptop
  - I'm currently polling the device for a valid input report, but the proper way would be using interrupts.
2. Design an enclosure that packages the touchpad device and Raspberry Pi Pico together.
  - shorter ZIF cable would be nice. Or it can be wrapped around like in the [Peacock touchpad](https://github.com/george-norton/peacock/commits?author=george-norton)
  - I only need 5 pins out of the 51 pin ZIF connector. Breakout board can be slimmed down to only have ZIF connector and the relevant pins.
    - custom PCB route; how do I solder ZIF connector?
  - Likewise, I don't need all of the features and pins available on Raspberry Pi Pico. Microcontroller board could be slimmed down to only include the necessary bits
    - again, custom PCB route; should be able to directly route touchpad pins to RP2040
    - USB C would be nice
3. Wireless communication?
  - ESP32? Bluetooth? More to learn in this front

Slight complication: the touchpad works on Linux, but not on Windows. 

# 12/29/2024 
Been brainstorming how to get the hardware side of things integrated. Touchpad uses 51 pin 0.3mm pitch Flexible Flat Cable, though I only need at most 5 pins out of 51. 
If I don't want to use the giant breakout board, I need to solder the FFC connector which sounds like a lot of pain. It's not only SMD, but also painfully tiny and I doubt I can manage it by hand. 

Another alternative is using a slightly larger pitch. 51 pin 0.3 mm pitch to 51 pin 0.5mm pitch cable is available, and 0.5 mm pitch connector sounds slightly more manageable. From what I gathered online, I should be able to hand solder or use hot air gun to get it done with a lot of flux and solder paste.

Or I could live with the breakout board which already has the connector soldered, and maybe fold the FFC two times (90 degrees to the right then immediately 90 degrees to the left) to shorten the cable connection. Shortest cable I could find on AliExpress was 40mm, and the majority of vendors sell 60mm+ cables only. 

I could design a custom RP2040 board which uses the breakout board as a hat, although having a FPC connector and pins directly routed on my custom board is the best solution. 

I also learned that Framework 16's touchpad module does not use this 51 pin FFC to talk to the mother board. The key I2C and power pins are directly connected via the input module interface in the 16" model. That would be easier to work with, since I can even directly solder wires to those exposed pins, but I don't want to order a new module if possible. 

Enclosure for the touchpad (3D Print)
- slightly angled 
- probably won't have too much room inside... 
- mount the touchpad to the enclosure

Option 1. Use the breakout board or use the off the shelf RPi Pico board
1.1. Design a RP2040 board clone about the same size of the breakout board. Breakout board will be mounted to this custom board. 
1.2. Cut the breakout board to reduce footprint, solder 5 pins to the slots I need
1.3. Use RPi Pico (or equivalent) - [Waveshare RP2040-Zero](https://www.waveshare.com/wiki/RP2040-Zero) for smaller footprint?

Option 2. Design everything from scratch 
2.1 Need to order more cable (in case I mess up), FFC connector, FFC Converter
2.2 Need to order soldering iron tip for fine work (hook? knife?), thinner gauge solder wire, solder paste, flux (Though flux would be good to have in general). Can use heat gun at the maker space 
2.3 Need to order individual components for the RPi Pico clone boards and solder everything together 

:thinking_face: 

Touchpad might also not work on Windows because I don't have the driver. If that's the case, what do I need for Windows to make it recognize this as a touchpad? Also is my thing working on Framework device because it already has a Framework's touchpad installed and configured in it?

Confirmed that it works on a NixOS system; Framework said their touchpad driver is available in the kernel, so that must be why. 

So the reason this is not working on Windows is likely because of the missing driver...

Got the interrupt code working. Not sure why the same code wasn't working before. However the current interrupt code is barely usable. It does not register cursor movements well at all. My guess is either I have some kind of bouncing, or the rate is off. 

Progress nonetheless. 

I need to send multiple report over time. Is interrupt choking the reports sent from the device? 

TODO: check the benchmark data rate from the laptop, and tweak the device to match that; 

TODO: Read more on how I2C interrupt is supposed to work. Does it make sense to send in the interrupt callback? 

# 12/30/2024

There might be some choking happening from the irq. 

Also, maybe the interrupt is intended for the host system to use, not the microcontroller that's working as a bridge. 

Polling is working a-ok... for now... 

Bugs found so far: 

Polling: 
- Sometimes one of the finger gets "locked," causing the gestures to go all haywire
  - could add a button to reset
  - or fix the report registration 
- When scrolling, lift all fingers, and then click on a different spot on the touchpad, cursor sometimes jumps to the different spot. It thinks I scrolled to that location instead of registering it as click. 
- Click sometimes needs some attempts to actually register

Interrupt: 
- Cannot move cursors at all. Clicks and Double clicks sometimes work

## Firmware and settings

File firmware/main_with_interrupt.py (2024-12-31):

from micropython import const
from usb.device.hid import HIDInterface
import machine
import struct
import usb.device
import time

SDA_PIN = machine.Pin(4)
SCL_PIN = machine.Pin(5)

INT_PIN = machine.Pin(14, machine.Pin.IN, machine.Pin.PULL_UP)
IS_DEBUG = False

TOUCHPAD_ADDR = 0x2C
REPORT_ID = 0x01
_INTERFACE_PROTOCOL_MOUSE = const(0x02)
_TOUCH_PAD_REPORT_DESC = (
    b'\x05\x01\x09\x02\xA1\x01\x85\x02\x05\x01\x09\x01\xA1\x00\x05\x09\x19\x01\x29\x02\x15\x00\x25\x01\x75\x01\x95\x02\x81\x02\x05\x0D\x09\x32\x75\x01\x95\x01\x81\x02\x75\x05\x95\x01\x81\x03\x05\x01\x75\x10\x95\x01\x35\x00\x45\x00\x16\x00\x80\x26\xFF\x7F\x09\x30\x81\x26\x16\x00\x80\x26\xFF\x7F\x09\x31\x81\x26\xC0\xC0\x05\x0D\x09\x05\xA1\x01\x85\x01\x05\x0D\x09\x22\xA1\x02\x09\x47\x09\x42\x15\x00\x25\x01\x75\x01\x95\x02\x81\x02\x95\x06\x81\x03\x09\x51\x25\x0F\x75\x08\x95\x01\x81\x02\x05\x01\x09\x30\x75\x10\x55\x0E\x65\x11\x35\x00\x46\x5A\x04\x27\x39\x05\x00\x00\x81\x02\x09\x31\x46\xDA\x02\x27\x6C\x03\x00\x00\x81\x02\xC0\x05\x0D\x09\x22\xA1\x02\x09\x47\x09\x42\x15\x00\x25\x01\x75\x01\x95\x02\x81\x02\x95\x06\x81\x03\x09\x51\x25\x0F\x75\x08\x95\x01\x81\x02\x05\x01\x09\x30\x75\x10\x55\x0E\x65\x11\x35\x00\x46\x5A\x04\x27\x39\x05\x00\x00\x81\x02\x09\x31\x46\xDA\x02\x27\x6C\x03\x00\x00\x81\x02\xC0\x05\x0D\x09\x22\xA1\x02\x09\x47\x09\x42\x15\x00\x25\x01\x75\x01\x95\x02\x81\x02\x95\x06\x81\x03\x09\x51\x25\x0F\x75\x08\x95\x01\x81\x02\x05\x01\x09\x30\x75\x10\x55\x0E\x65\x11\x35\x00\x46\x5A\x04\x27\x39\x05\x00\x00\x81\x02\x09\x31\x46\xDA\x02\x27\x6C\x03\x00\x00\x81\x02\xC0\x05\x0D\x09\x22\xA1\x02\x09\x47\x09\x42\x15\x00\x25\x01\x75\x01\x95\x02\x81\x02\x95\x06\x81\x03\x09\x51\x25\x0F\x75\x08\x95\x01\x81\x02\x05\x01\x09\x30\x75\x10\x55\x0E\x65\x11\x35\x00\x46\x5A\x04\x27\x39\x05\x00\x00\x81\x02\x09\x31\x46\xDA\x02\x27\x6C\x03\x00\x00\x81\x02\xC0\x05\x0D\x09\x22\xA1\x02\x09\x47\x09\x42\x15\x00\x25\x01\x75\x01\x95\x02\x81\x02\x95\x06\x81\x03\x09\x51\x25\x0F\x75\x08\x95\x01\x81\x02\x05\x01\x09\x30\x75\x10\x55\x0E\x65\x11\x35\x00\x46\x5A\x04\x27\x39\x05\x00\x00\x81\x02\x09\x31\x46\xDA\x02\x27\x6C\x03\x00\x00\x81\x02\xC0\x05\x0D\x09\x54\x15\x00\x25\x05\x75\x08\x95\x01\x81\x02\x05\x09\x09\x01\x09\x02\x09\x03\x15\x00\x25\x01\x75\x01\x95\x03\x81\x02\x95\x05\x81\x03\x05\x0D\x09\x56\x55\x0C\x66\x01\x10\x35\x00\x47\xFF\xFF\x00\x00\x15\x00\x27\xFF\xFF\x00\x00\x75\x10\x95\x01\x81\x02\x05\x0D\x09\x55\x15\x00\x25\x05\x75\x08\x95\x01\x85\x03\xB1\x02\x05\x0D\x09\x59\x15\x00\x25\x0F\x75\x08\x95\x01\x85\x04\xB1\x02\x06\x00\xFF\x85\x05\x75\x08\x15\x00\x09\xC6\x25\x08\x95\x01\xB1\x02\x09\xC7\x26\xFF\x00\x95\x20\xB1\x02\xC0\x05\x0D\x09\x0E\xA1\x01\x05\x0D\x09\x22\xA1\x02\x09\x52\x15\x00\x25\x0A\x75\x08\x95\x01\x85\x06\xB1\x02\xC0\x05\x0D\x09\x22\xA1\x00\x09\x57\x09\x58\x15\x00\x25\x01\x75\x01\x95\x02\x85\x07\xB1\x02\x95\x06\xB1\x03\xC0\x05\x0D\x09\x60\x15\x00\x25\x01\x75\x01\x95\x01\x85\x08\xB1\x02\x95\x07\xB1\x03\xC0\x06\x00\xFF\x09\x01\xA1\x01\x85\x42\x09\x06\x15\x00\x26\xFF\x00\x75\x08\x95\x03\xB1\x02\x06\x00\xFF\x09\x05\x15\x00\x26\xFF\x00\x75\x08\x96\x00\x01\x85\x41\xB1\x02\x85\x43\x09\x06\x15\x00\x26\xFF\x00\x75\x08\x95\x03\xB1\x02\xC0'
)

i2c = machine.I2C(0, sda=SDA_PIN, scl=SCL_PIN, freq=1000000)


class TouchPadInterface(HIDInterface):
    def __init__(self, interface_str="Standalone Framework Touchpad"):
        super().__init__(
            _TOUCH_PAD_REPORT_DESC,
            protocol=_INTERFACE_PROTOCOL_MOUSE,
            interface_str=interface_str
        )
        self._buf = bytearray(35)

    
    def send_report(self, report):     
        struct.pack_into('35B', self._buf, 0, REPORT_ID, *report)
        if IS_DEBUG:
            print(' '.join('{:02x}'.format(x) for x in self._buf))
        else:
            return super().send_report(self._buf)
    
    # TODO: Somewhat works; can send the report, but it isn't working as nicely. Rate? Bouncing? 
    def callback(self, pin):
        # Code for fetching the report from https://hackaday.com/2024/04/17/human-interfacing-devices-hid-over-i2c/
        report_len = i2c.readfrom(TOUCHPAD_ADDR, 1)[0]
        if report_len:
            report = i2c.readfrom(TOUCHPAD_ADDR, report_len)
            if report[2] == REPORT_ID:                    
                report = report[3:]
                self.send_report(report)

            
def runner():
    
    TP = TouchPadInterface()
    INT_PIN.irq(trigger=machine.Pin.IRQ_FALLING, handler=TP.callback)
    
    if not IS_DEBUG:
        usb.device.get().init(TP, builtin_driver=True)

    # wait for host to enumerate as a HID device
    while not TP.is_open():
        time.sleep_ms(100)
       
    pass


runner()

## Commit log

2024-12-26 Start working on PCB design
    [framework-touchpad.kicad_pcb, framework-touchpad.kicad_sch]
2024-12-30 Work on KiCad; Add more submodule; Update journal
    [framework-touchpad.kicad_pcb, framework-touchpad.kicad_sch]
2024-12-30 Add MVP for interrupt method; rename existing main to main_with_polling
2024-12-30 Fix interrupt firmeware to properly use the handler; Update firmware directory link in README; Update Journal entry
    [main_with_callback.py]
2024-12-31 Update README; Add entry to journal; Clean up polling and interrupt code
2025-10-26 Document HID descriptor availability from Framework
    Added update about HID descriptor and report definitions.
2026-02-24 Add 3d print models
    [Touchpad Enclosure - Bottom plate.3mf, Touchpad Enclosure - Enclosure.3mf, Touchpad Enclosure - Top Cover.3mf]
